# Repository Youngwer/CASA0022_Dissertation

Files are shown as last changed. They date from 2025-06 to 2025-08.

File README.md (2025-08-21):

# 🌊 AquaMonitor: Portable LoRaWAN Water Quality Monitoring System






> A portable, real-time drinking water quality monitoring system designed for public spaces, featuring multi-parameter sensing, LoRaWAN connectivity, and comprehensive web-based data visualization.

📖 **[View Full Dissertation](./Portable%20LoRaWAN-Based%20Real-Time%20Water%20Quality.pdf)

## 🎯 Project Overview

This system addresses the critical need for real-time water quality monitoring in public drinking facilities. Unlike traditional laboratory-based testing that can take hours or days, AquaMonitor provides **immediate water safety assessment** through:

- **Multi-parameter sensing**: pH, turbidity, electrical conductivity, and temperature
- **Instant feedback**: Tri-color LED indicators and e-paper display
- **Long-range connectivity**: LoRaWAN communication via The Things Network
- **Public accessibility**: Web dashboard for community monitoring
- **Portable design**: Battery-powered operation for diverse deployment scenarios
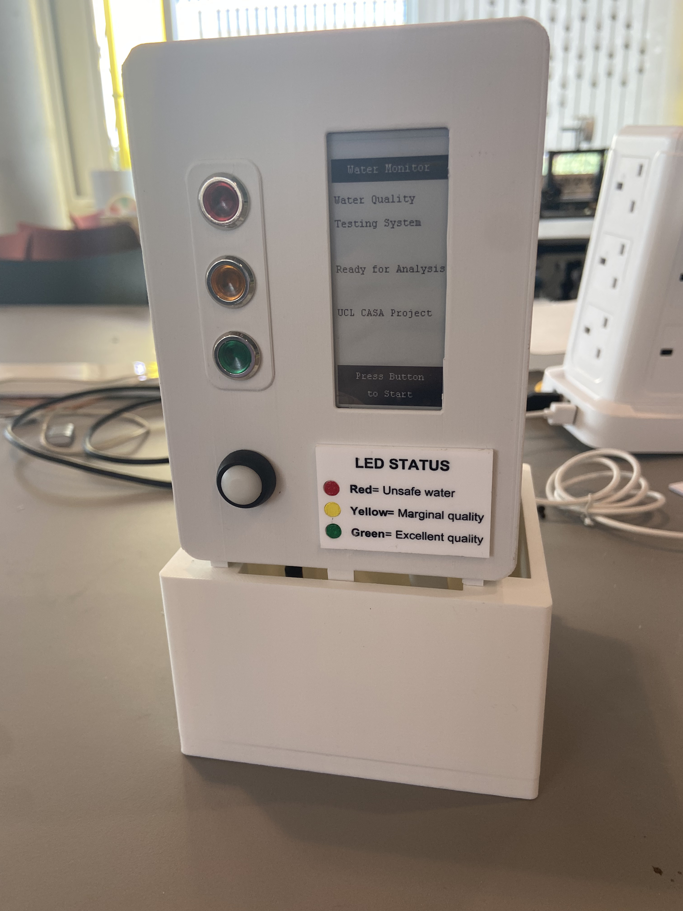
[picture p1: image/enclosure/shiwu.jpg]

### 🏆 Key Achievements
- ✅ **100% classification accuracy** according to WHO/EPA standards
- ✅ **Excellent sensor calibration** (R² = 0.9995 for pH, R² = 0.9987 for turbidity)
- ✅ **Comprehensive dataset** from UCL East Marshgate area public facilities
- ✅ **Real-time response** within 3-5 seconds of sensor immersion

## 🚀 Features

### Hardware Capabilities
- **Multi-sensor Integration**: 4 calibrated sensors for comprehensive water analysis
- **Immediate Visual Feedback**: LED indicators (🔴 Unsafe, 🟡 Marginal, 🟢 Excellent)
- **Detailed Display**: 2.9" e-paper screen with parameter readings
- **Robust Design**: 3D-printed waterproof enclosure with rubber grommets
- **Long-range Communication**: LoRaWAN connectivity (5-15km range)

### Software Features
- **Real-time Classification**: WHO/EPA standard-based water safety assessment
- **Web Dashboard**: Public access to current and historical data
- **Source Tracking**: Categorize and compare different water facilities
- **Mobile Responsive**: Optimized for both desktop and mobile viewing

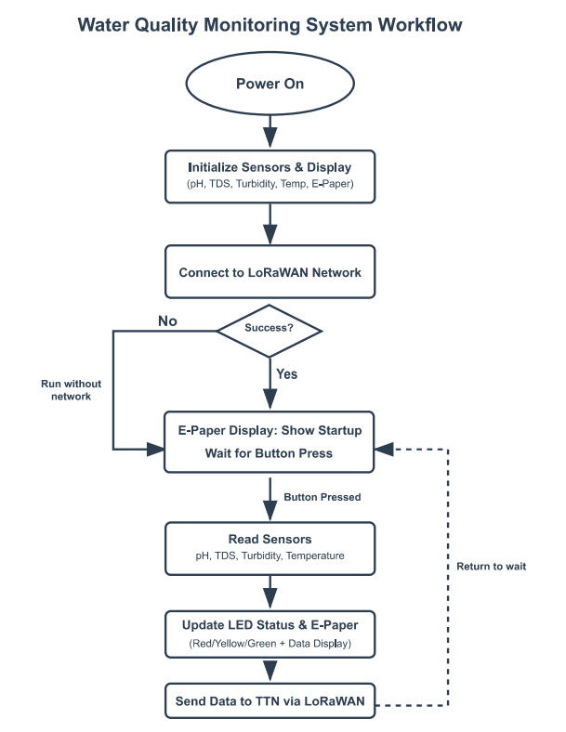
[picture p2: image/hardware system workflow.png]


## 🏗️ System Architecture

### Data Flow
```
Sensors → Arduino MKR WAN 1310 → LoRaWAN → TTN → Webhook → PostgreSQL → Web App
```

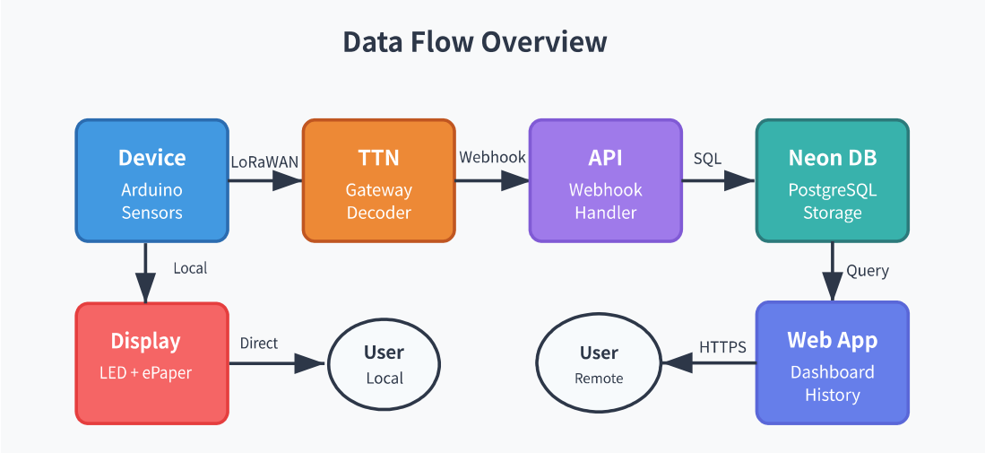
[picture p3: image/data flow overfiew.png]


### Component Overview

| Component | Function | Communication |
|---|---|---|
| **Sensors** | Water parameter measurement | Analog/Digital |
| **Arduino MKR WAN 1310** | Data processing & transmission | LoRaWAN |
| **The Things Network** | LoRaWAN network server | HTTP Webhook |
| **Neon PostgreSQL** | Data storage | SQL |
| **Next.js Web App** | Data visualization | REST API |

## 🛠️ Hardware Requirements

### Core Components
- **Arduino MKR WAN 1310** - Main microcontroller with LoRaWAN
- **DFRobot SEN0161** - pH sensor (±0.1 pH accuracy)
- **DFRobot SEN0189** - Turbidity sensor (0-1000 NTU range)
- **Conductivity Probe** - EC/TDS measurement (±2% reading accuracy)
- **DS18B20** - Waterproof temperature sensor (±0.5°C accuracy)

### Interface Components
- **2.9" E-Paper Display** - Low power consumption display
- **Tri-color LEDs** - Immediate visual feedback
- **Waterproof Push Button** - User interaction
- **3D Printed Enclosure** - Weather-resistant housing

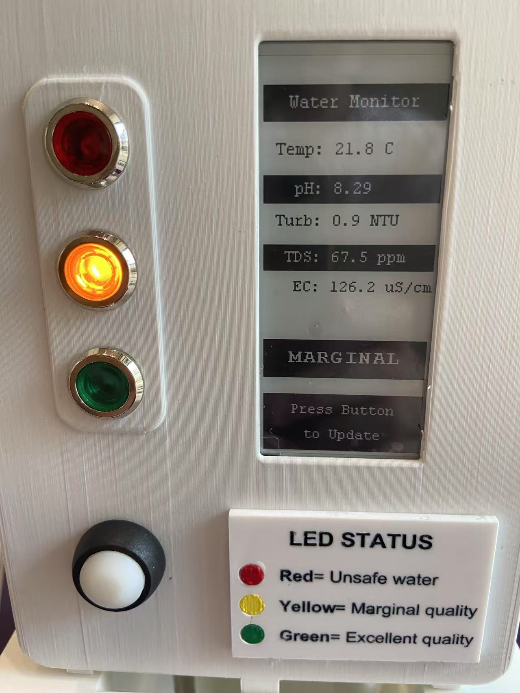
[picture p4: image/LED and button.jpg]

## 💻 Software Requirements

### Development Environment
- **Arduino IDE** 1.8.x or 2.x
- **Node.js** 18.x or later
- **Git** for version control

### Required Libraries

#### Arduino Libraries
```cpp
#include <MKRWAN.h>           // LoRaWAN communication
#include <OneWire.h>          // Temperature sensor
#include <DallasTemperature.h> // DS18B20 interface
#include <GxEPD2_BW.h>        // E-paper display
#include <Fonts/FreeMonoBold9pt7b.h>
```

#### Web Application Dependencies
```json
{
  "next": "^14.0.0",
  "react": "^18.0.0",
  "pg": "^8.11.0",
  "@vercel/postgres": "^0.5.0"
}
```

## 📥 Installation & Setup

### 1. Hardware Assembly

#### Sensor Connections
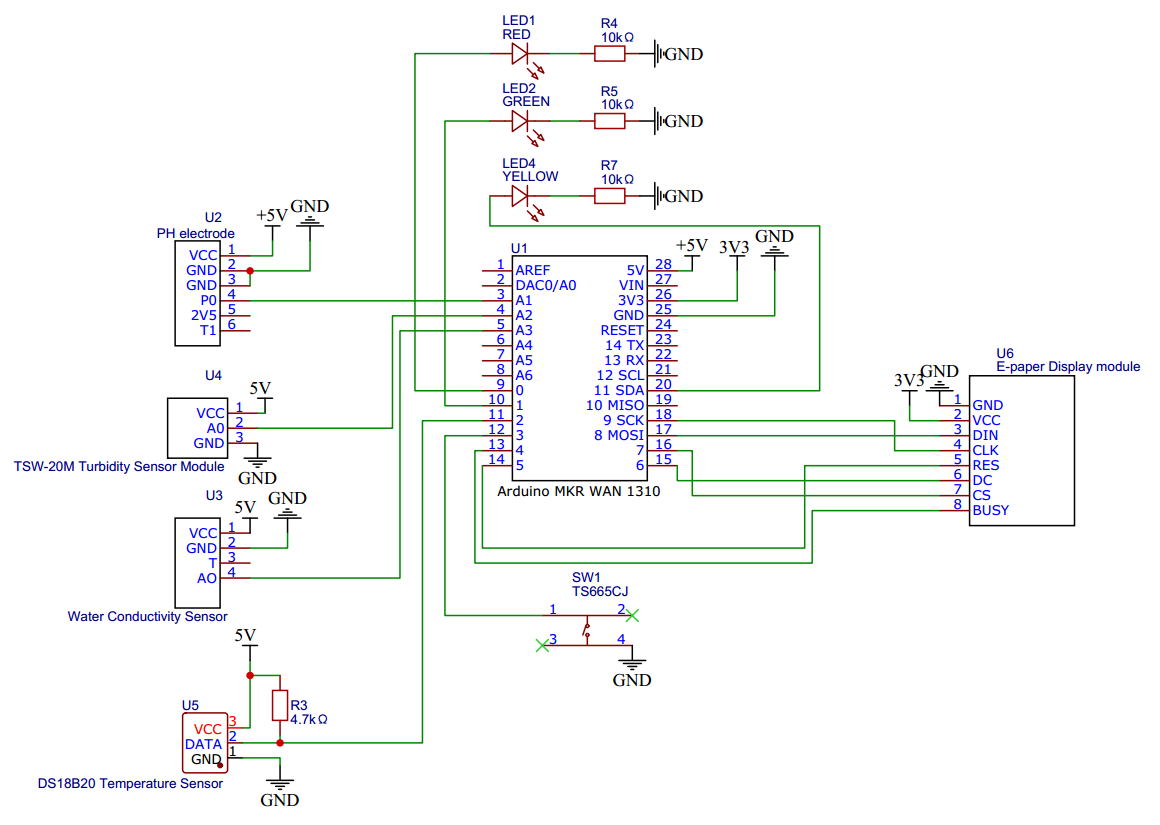
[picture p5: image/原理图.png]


| Component | Arduino Pin | Notes |
|---|---|---|
| pH Sensor | A1 | 5V power required |
| Turbidity Sensor | A2 | Via voltage divider (6.4kΩ + 6.4kΩ) |
| EC Sensor | A0 | Direct connection |
| Temperature Sensor | D6 | 4.7kΩ pull-up resistor |
| Red LED | D2 | 10kΩ current limiting resistor |
| Green LED | D3 | 10kΩ current limiting resistor |
| Yellow LED | D4 | 10kΩ current limiting resistor |
| Push Button | D1 | Pull-down configuration |
| E-Paper Display | SPI | Multiple pins (see Table 5) |

#### Enclosure 
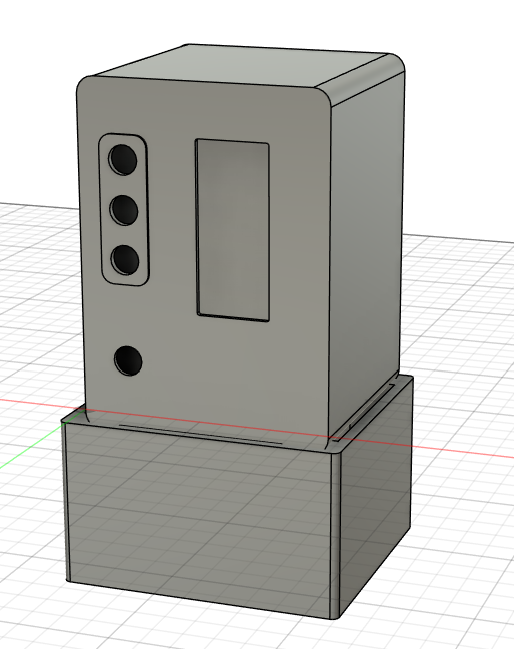
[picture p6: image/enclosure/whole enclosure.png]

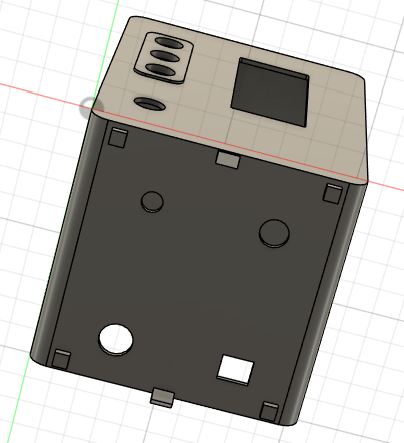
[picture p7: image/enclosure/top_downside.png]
- **Upper Housing**
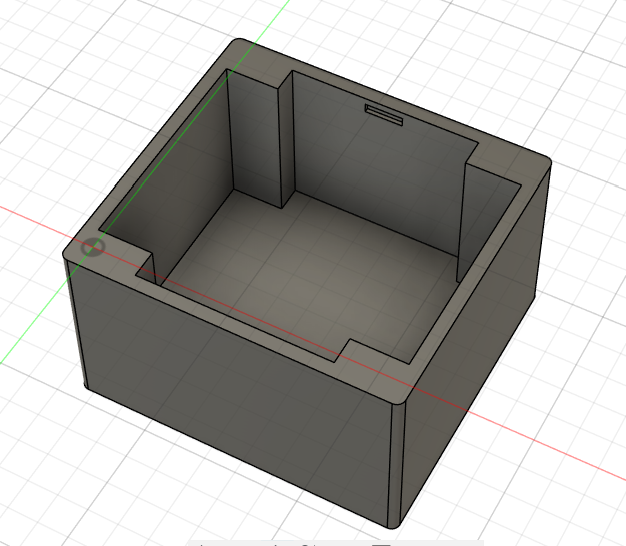
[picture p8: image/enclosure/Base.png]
- **Lower Base** 
- **Print Settings**: PLA, 0.2mm layer height, 20% infill

### 2. Arduino Setup

#### LoRa: Get Device EUI
```cpp
// Run this code first to get your DevEUI
#include <MKRWAN.h>
LoRaModem modem;

void setup() {
  Serial.begin(115200);
  if (!modem.begin(EU868)) {
    Serial.println("Failed to start module");
    while(1) {}
  };
  Serial.print("Your device EUI is: ");
  Serial.println(modem.deviceEUI());
}
```

#### Sensor Calibration

**pH Sensor Calibration**
```cpp
// Calibration equation derived from standard buffer solutions
// pH = 12.521 × Voltage - 17.79
// R² = 0.9995
```

**Turbidity Sensor Calibration**
```cpp
// Calibration equation from standard solutions
// NTU = -142.68 × Voltage + 638.92
// R² = 0.9987
```
### 3. The Things Network Configuration

#### Device Registration
1. Create account at [The Things Network](https://www.thethingsnetwork.org/)
2. Create new application: `water-quality-monitor`
3. Register device with retrieved DevEUI
4. Set frequency plan to EU868
5. Note down AppKey and AppEUI

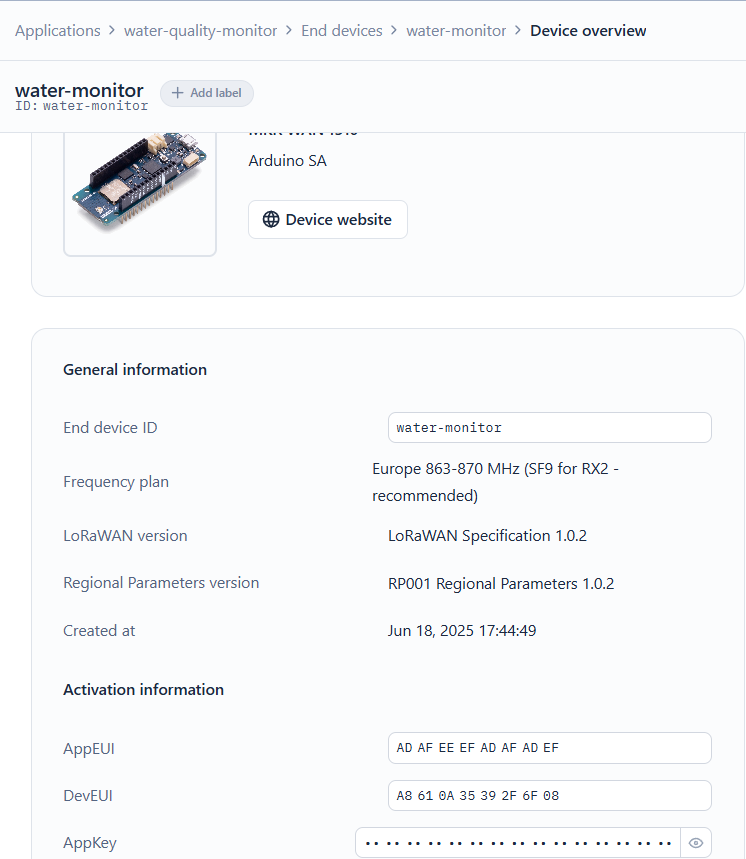
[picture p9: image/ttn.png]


#### Payload Formatter
```javascript
function decodeUplink(input) {
  var data = {};
  data.ph = ((input.bytes[0] << 8) | input.bytes[1]) / 100.0;
  data.turbidity = ((input.bytes[2] << 8) | input.bytes[3]) / 100.0;
  data.tds = (input.bytes[4] << 8) | input.bytes[5];
  data.ec = (input.bytes[6] << 8) | input.bytes[7];
  data.temperature = ((input.bytes[8] << 8) | input.bytes[9]) / 100.0;
  data.status = String.fromCharCode(input.bytes[10]);
  
  return {
    data: data,
    warnings: [],
    errors: []
  };
}
```

### 4. Database Setup

#### Neon PostgreSQL
1. Create account at [Neon](https://neon.tech/)
2. Create new database: `water_quality_monitor`
3. Run schema setup:

```sql
CREATE TABLE measurements (
  id SERIAL PRIMARY KEY,
  ph DECIMAL(4,2),
  turbidity DECIMAL(6,2),
  tds INTEGER,
  ec INTEGER,
  temperature DECIMAL(4,2),
  status VARCHAR(10),
  water_source VARCHAR(100),
  timestamp TIMESTAMPTZ DEFAULT NOW()
);

CREATE INDEX idx_timestamp ON measurements(timestamp);
CREATE INDEX idx_status ON measurements(status);
```

### 5. Web Application Deployment

#### Local Development
```bash
# Clone repository
git clone https://github.com/Youngwer/CASA0022_Dissertation.git
cd CASA0022_Dissertation/web

# Install dependencies
npm install

# Set environment variables
cp .env.example .env.local
# Edit .env.local with your database URL

# Run development server
npm run dev
```

#### Vercel Deployment
```bash
# Install Vercel CLI
npm i -g vercel

# Deploy
vercel --prod
```

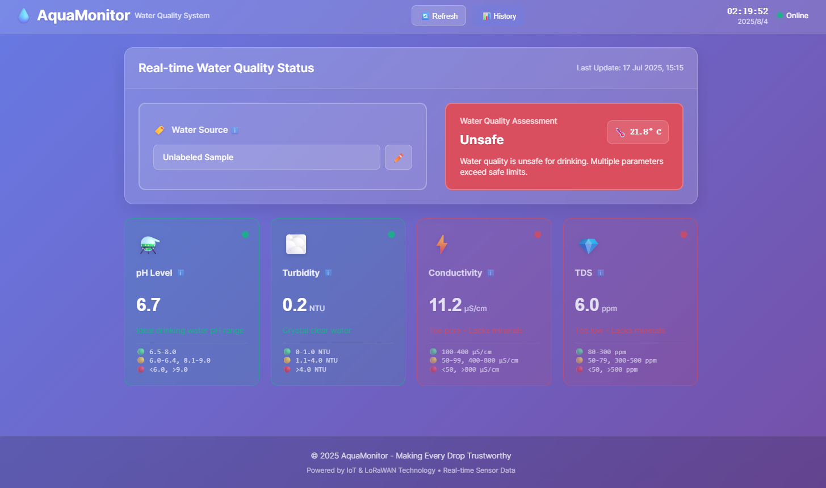
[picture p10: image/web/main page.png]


## 🔧 Usage Instructions

### Device Operation

1. **Power On**: Connect USB power supply
2. **Wait for Initialization**: E-paper displays home screen
3. **Immerse Sensors**: Place all four sensors in water sample
4. **Press Button**: Activate measurement cycle
5. **Read Results**: 
   - LED color indicates overall water safety
   - E-paper shows detailed parameters
   - Data automatically transmitted via LoRaWAN

### Water Quality Classification

| Status | LED Color | Criteria |
|---|---|---|
| **Excellent** | 🟢 Green | All parameters within optimal WHO ranges |
| **Marginal** | 🟡 Yellow | Safe but some parameters in acceptable ranges |
| **Unsafe** | 🔴 Red | One or more parameters exceed safety limits |

#### Parameter Thresholds

| Parameter | Excellent | Marginal | Unsafe |
|---|---|---|---|
| pH | 6.5 - 8.0 | 6.0-6.4, 8.1-9.0 | <6.0, >9.0 |
| Turbidity (NTU) | 0 - 1.0 | 1.1 - 4.0 | >4.0 |
| TDS (ppm) | 80 - 300 | 50-79, 301-500 | <50, >500 |
| EC (μS/cm) | 100 - 400 | 50-99, 401-800 | <50, >800 |

### Web Dashboard Features

- **Real-time Status**: Current water quality with color-coded background
- **Parameter Details**: Individual sensor readings with timestamps
- **Historical Data**: Sortable table of past measurements
- **Source Tracking**: Filter by water source type
- **Data Export**: Download CSV for further analysis

## 📁 Repository Structure

```
CASA0022_Dissertation/
├── arduino/
│   ├── device_main/              # Main device firmware
│   │   └── device_main.ino
│   ├── sensor_tests/             # Individual sensor test codes
│   │   ├── ph_test.ino
│   │   ├── turbidity_test.ino
│   │   ├── ec_test.ino
│   │   └── temperature_test.ino
│   └── calibration/              # Sensor calibration utilities
│       ├── ph_calibration.ino
│       └── turbidity_calibration.ino
├── web/
│   ├── components/               # React components
│   ├── pages/                    # Next.js pages
│   ├── styles/                   # CSS stylesheets
│   ├── utils/                    # Utility functions
│   └── public/                   # Static assets
├── hardware/
│   ├── 3d_models/               # STL files for enclosure
│   │   ├── upper_housing.stl
│   │   └── lower_base.stl
│   ├── schematics/              # Circuit diagrams
│   └── pcb/                     # PCB design files (if applicable)
├── docs/
│   ├── Dissertation.pdf         # Complete dissertation
│   ├── calibration_guide.md     # Sensor calibration procedures
│   ├── deployment_guide.md      # Field deployment instructions
│   └── troubleshooting.md       # Common issues and solutions
├── data/
│   ├── sample_dataset.csv       # Example measurement data
│   └── calibration_data/        # Sensor calibration records
└── README.md
```

## 🌍 Deployment Locations

This system has been successfully tested across diverse public facilities in the UCL East Marshgate area:

- **University Campus**: Water fountains and bathroom taps
- **Shopping Centers**: Westfield Avenue public fountains  
- **Public Parks**: Queen Elizabeth Olympic Park facilities
- **Commercial Areas**: Various retail space water sources

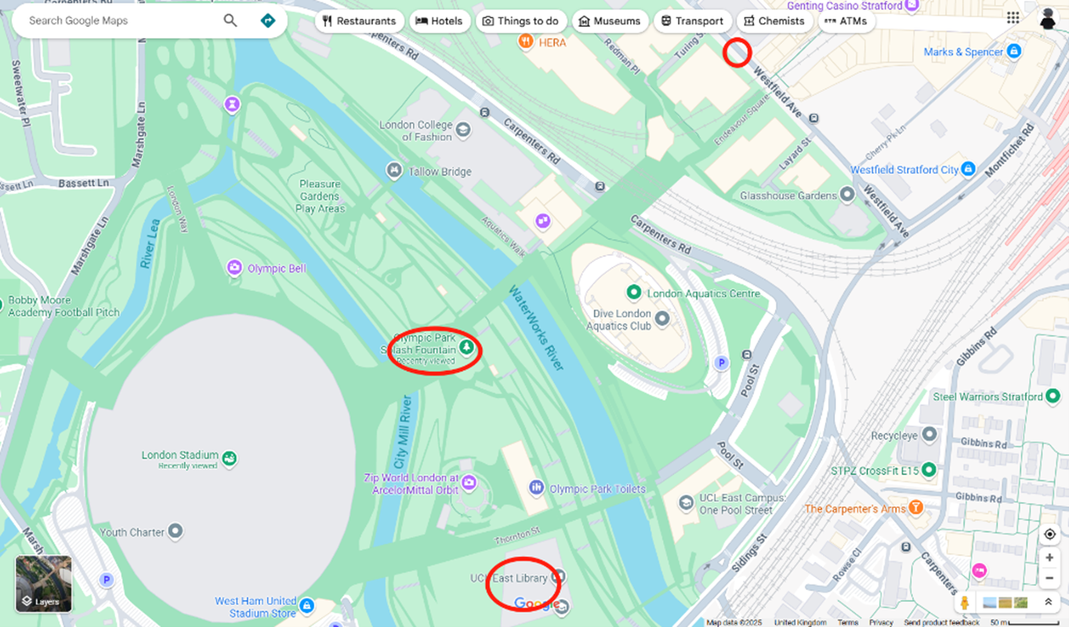
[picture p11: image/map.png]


### Field Testing Results

| Location | Water Quality | Key Findings |
|---|---|---|
| UCL Marshgate Fountain | Excellent | Consistent 🟢 ratings across multiple tests |
| Olympic Park Plaza | Excellent | Slightly higher TDS than campus sources |
| Westfield Public Fountain | Excellent | Higher mineral content (245 ppm TDS) |
| Campus Bathroom Tap | Excellent | Similar quality to fountain sources |

## 🤝 Contributing

We welcome contributions to improve AquaMonitor! Here's how you can help:

### Improvements
- Additional sensor integration
- Weatherproofing enhancements
- Mobile application development

### How to Contribute
1. Fork the repository
2. Create a feature branch (`git checkout -b feature/AmazingFeature`)
3. Commit your changes (`git commit -m 'Add some AmazingFeature'`)
4. Push to the branch (`git push origin feature/AmazingFeature`)
5. Open a Pull Request

## 📊 Performance Metrics

### Sensor Accuracy
- **pH Sensor**: ±0.13 pH units (±3.25% max error)
- **Turbidity Sensor**: ±1.68 NTU (±3.65% max error)  
- **Temperature Sensor**: ±0.5°C (manufacturer specification)
- **EC Sensor**: ±2% reading (manufacturer specification)

### System Performance
- **Response Time**: 3-5 seconds for complete measurement
- **Classification Accuracy**: 100% according to WHO/EPA standards
- **LoRaWAN Range**: Successfully tested up to 2km radius
- **Data Transmission**: 100% success rate across test locations

### Power Consumption
- **Measurement Mode**: ~150mA (USB powered)
- **Sleep Mode**: <1mA (future battery implementation)
- **Display Update**: ~50mA for 2 seconds

## 🛠️ Troubleshooting

### Common Issues

#### Sensor Reading Errors
- **pH Probe**: Ensure proper conditioning in storage solution
- **Turbidity Sensor**: Check voltage divider connections
- **EC Sensor**: Verify probe cleanliness and calibration
- **Temperature**: Confirm OneWire library installation

#### Web Dashboard Issues
- Check environment variables in `.env.local`
- Verify database connection string
- Ensure webhook URL matches deployment URL

### Calibration Maintenance
- **pH Sensor**: Recalibrate monthly with buffer solutions
- **Turbidity Sensor**: Clean optical surfaces weekly
- **EC Sensor**: Use standard conductivity solutions for verification
- **All Sensors**: Store properly when not in use

## 📄 License

This project is licensed under the MIT [License](https://opensource.org/license/mit).

## 📞 Contact & Support

**Author**: Wenhao Yang  
**Institution**: UCL Centre for Advanced Spatial Analysis  
**Supervisor**: Martin de Jode  
**Module**: CASA0022 - Connected Environments MSc

### Get in Touch
- 📧 **Email**: ucfnwy2@ucl.ac.uk
- 🐱 **GitHub**: [@Youngwer](https://github.com/Youngwer)
- 📄 **Dissertation**: [Full PDF](./Portable%20LoRaWAN-Based%20Real-Time%20Water%20Quality.pdf)
- 🐛 **Bug Reports**: [GitHub Issues](https://github.com/Youngwer/CASA0022_Dissertation/issues)

---

## 🙏 Acknowledgments

Special thanks to:
- **Martin de Jode** - Project supervisor and technical guidance
- **Danny Steadman & Simon Gosling** - Light Fabrication Workshop support
- **UCL CASA** - Facilities and equipment access
- **The Things Network** - LoRaWAN infrastructure
- **Open Source Community** - Libraries and tools

---

<div align="center">

**🌊 Making water quality monitoring accessible to everyone 🌊**

[⬆ Back to Top](#-aquamonitor-portable-lorawan-water-quality-monitoring-system)

</div>

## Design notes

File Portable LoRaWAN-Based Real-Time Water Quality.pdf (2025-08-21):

## Portable LoRaWAN-Based Real-Time Drinking

## Water Quality Monitoring System for Public

## Spaces

## Author: Wenhao Yang

## Supervisor: Martin de Jode

## Module: CASA0022

### Github Repo: https://github.com/Youngwer/CASA0022_Dissertation

## Wordcount: 5798

- [excluding tables, figures, captions, title page,

### acknowledgements, references, abstract and appendices]

### This dissertation is submitted in part requirement for the MSc in the

### Centre for Advanced Spatial Analysis, Bartlett Faculty of the Build

Environment, UCL.

## Declaration of Authorship:

### I, Wenhao Yang, confirm that the work presented in this assessment is my

own and that all sources have been acknowledged.

### ASSESSMENT DATE: 22/08/2025

## Abstract

Access to safe drinking water remains a global issue, with approximately 2 billion

people relying on contaminated drinking water sources according to the World Health

Organization. Public drinking facilities, such as water fountains in universities, parks,

and commercial spaces, often lack real-time water quality assessment, instead, relying

heavily on periodic laboratory testing which is time-consuming and may not detect

contamination immediately.

Studies have shown that Internet of Things (IoT) technologies have the potential to

offer continuous and automated surveillance that would improve the safety of the

overall health of the public. Due to the widespread distribution of public drinking

facilities, the deployment of drinking water monitoring devices is hard to achieve

comprehensive coverage as this device are usually fixed and expensive.

This paper presents an innovative portable monitoring system integrating multiple

sensors (pH, turbidity, electrical conductivity, temperature) with LoRaWAN

communication to The Things Network (TTN). The low-cost IoT device features

multi-level user interaction through LED indicators, e-paper display, and web

dashboard, providing immediate water quality assessment based on WHO standards

and categorizing safety as “Excellent”, “Marginal”, “Unsafe”. The effectiveness of the

system has been demonstrated in the field testing across UCL East area drinking

points with successful testing results gained for public space implementation.

## Acknowledgements

I would like to express my gratitude to my supervisor, Martin de Jode, for his constant

inspiration and assistance throughout this process. His invaluable design advice,

encouragement, detailed guidance in providing appropriate equipment, and

comprehensive thesis supervision have been instrumental in the successful completion

of this project.

I would also like to thank Danny Steadman and Simon Gosling from the Light

Fabrication Workshop for their expert assistance with the 3D printing enclosure and

their support during the exhibition phase of this research.

## 1. Introduction

### 1.1 Research Background

In the United Kingdom, drinking water quality is generally maintained at a high

standard, with public water supply systems achieving a compliance rate of over

99.98%(Drinking Water Inspectorate, 2024). However, challenges exist, particularly

with public drinking facilities such as water fountains and taps, which can pose health

risks if not properly maintained.

Research indicates that inadequate cleaning can lead to bacterial contamination in

these facilities, especially in high-traffic areas like schools, parks, and train stations

(The Guardian, 2018). Additionally, aging infrastructure, such as lead pipes in older

buildings, contributes to localised contamination risks, with lead compliance rates

slightly lower at 99.6%(Drinking Water Inspectorate, 2024). Recent concerns have

also emerged regarding the presence of per- and polyfluoroalkyl substances (PFAS),

or “forever chemicals,” in some English drinking water sources, prompting calls for

stricter regulations(The Guardian, 2025).These issues highlight the need for enhanced

monitoring to ensure public water safety.

Public drinking fountains, as the main source for providing drinking water in the

public place, face significant safety concerns due to potential contamination. Studies

indicate that water fountains can harbour bacteria, and the bacterial colony counts in

public drinking fountains can be alarmingly high, particularly in high-traffic areas like

airports and shopping malls(Bichelman, 2024). For instance, a 2018 investigation

found that some public fountains in London had disappeared due to poor maintenance

and concern about health risks(The Guardian, 2018).

To solve the potential contamination problem of public facilities, water quality testing

is essential for the public health. Traditional laboratory-based water quality testing,

while essential, has notable limitations. This approach has several drawbacks,

including the high cost of labour and equipment, along with a lack of real-time

information about drinking water quality that can facilitate critical decisions to ensure

public safety(Vijayakumar and Ramya, 2015). Moreover, periodic sampling fails to

capture real-time fluctuations in water quality, limiting the ability to respond promptly

to contamination events(Zainurin et al., 2022). These limitations underscore the need

for more real-time monitoring solutions in public spaces.

This research aims to design and build a real-time water quality tester for public

drinking facilities through the communication of LoRaWAN with multi-parameter

sensors. The system shows water quality results via LED indicators and an e-paper

display for immediate feedback, alongside a web-based dashboard for detailed

visualization of water quality parameters. Public drinking fountains in the areas near

UCL East Marshgate were selected as the study area for this research. The project will

generate a dataset accessible in the project repository, with the assumption that the

information presented on the web dashboard may benefit stakeholders, including local

authorities and future water quality studies.

### 1.2 Research Questions and Objectives

1. Can a portable, low-cost, drinking water monitoring device be developed to

provide the public with immediate water quality safety information in urban areas

such as the UCL East Marshgate?

2. What are the water quality differences between different public drinking

facilities, such as university campus and commercial places, and can portable

monitoring effectively characterise these variations?

The objective of the project is to design and implement a portable, low-cost drinking

water quality monitoring system utilising LoRaWAN technology, alongside an

interactive web platform, to actively monitor and improve public awareness of water

quality safety at public drinking facilities near UCL East area.

### 1.3 Structure of the Dissertation

This dissertation is structured into six chapters, beginning with an Introduction

that outlines the research context and objectives. After the Introduction, a critical

review of literature on water quality monitoring and IoT-based sensor systems is

presented (Chapter 2), followed by a detailed design and implementation of the

portable drinking water monitoring system (Chapter 3), The collected data and

experimental results are presented in Chapter 4, with Chapter 5 discussing key

findings, limitations, and reflections, while Chapter 6 concluding this project while

identifying possible future research opportunities.

## 2. Literature Review

### 2.1 Water Quality Monitoring Methods: Evolution and Comparison

Drinking water quality monitoring is critical for safeguarding public health and

ensuring sustainable water resources. Since the late 20th century, drinking water quality

monitoring has evolved significantly, transitioning from reliance on traditional

laboratory testing to advanced, real-time technologies. Traditional methods, involving

chemical and biological analyses, offer high precision but are time-consuming and

costly (Vijayakumar and Ramya, 2015). The advent of electronic sensors enabled rapid

measurement of parameters like pH, turbidity, residual chlorine, and dissolved oxygen,

improving response times and data accuracy(Badger Meter, 2023). In the 21st century,

IoT technologies, leveraging low-power, long-range communication protocols such as

LoRaWAN and GSM, have transformed monitoring by enabling smart sensors to

transmit real-time data to cloud platforms, suitable for both urban and remote

settings(Zainurin et al., 2022). Remote sensing technologies, including satellites and

drones, have emerged as powerful tools for large-scale water quality assessment,

offering broad spatial coverage despite limitations in parameter specificity (Li et al.,

2021). Optical and spectroscopic methods, such as ultraviolet-visible spectroscopy

(UV-Vis) and fluorescence spectroscopy, offer non-invasive, rapid detection of turbidity,

dissolved organic matter, and microbial contaminants, minimizing chemical reagent use

(Jiang and Meng, 2015). The integration of artificial intelligence (AI) and machine

learning (ML) has further enhanced monitoring capabilities by enabling predictive

analytics and anomaly detection. These technologies analyse large datasets to identify

potential | contamination | risks | before | they | escalate, | improving | proactive

management(Zainurin et al., 2022). These advancements collectively underscore a shift

toward scalable, efficient systems prioritizing real-time data and public safety.

To comprehensively evaluate current drinking water quality monitoring strategies, the

following table compares five primary methods based on their advantages and

disadvantages.

Table 1. Summary of water quality monitoring approaches

Monitoring Method | Pros | Cons
Traditional Laboratory | High accuracy | Time-consuming, manual, high cost, less effective for continuous

Testing | | monitoring (Vijayakumar and Ramya, 2015)
On-Site Sensors | • Real-time data collection • monitors multiple parameters, • cost-effective(Badger Meter, 2023) | • Requires regular calibration and maintenance • accuracy may degrade over time • limited to specific parameters • needs power supply(Zainurin et al., 2022)
IoT Monitoring Systems | • Real-time wireless data transmission and quick alert • cost-effective in long-term | • Reliant on network coverage • potential cybersecurity risks • high initial investment(Fields, no date)
Remote Sensing | Large-scale and real-time monitoring and non-contact | • Limited parameter(turbidity and algae) measurement(NASA, 2023) • affected by weather and resolution, • high application cost(Yang et al., 2022)
Optical/Spectroscopic Methods | • High sensitivity and rapid • reagent-free detection of turbidity and organic matter • real-time monitoring(Thomas, Delpla and Thomas, 2017) | • Requires calibration • susceptible to interference • high equipment costs(Hossain et al., 2020)

### 2.2 Related Work

Recent research has demonstrated the technical feasibility of portable water quality

monitoring. Kelechi et al. (2021) developed portable systems integrating temperature,

pH, and turbidity sensors with microcontroller processing and Bluetooth connectivity

for Android applications, achieving high measurement accuracy (97-100%) while

demonstrating cost-effective monitoring capabilities for the community but suffering

from limited communication range(Hilary Kelechi et al., 2021). The WaterScope

platform by Bedell et al. (2024) further validated this approach through extensive

laboratory and field testing. Through the introduction of open-source portable testing

with machine learning-enhanced classification technology, it can establish equivalent

measurement with conventional laboratory methods(Dabrowska et al., 2024).

Most existing portable monitoring research focuses on natural water environments

such as rivers and lakes. Liu et al. (2018) developed a solar-powered LoRaWAN

system achieving stable data transmission every 30 minutes with minimal data loss,

though their focus remained on controlled water bodies rather than public drinking

facilities(Liu et al., 2018). Pires et al. (2024) implemented practical river monitoring

solutions measuring temperature, pH, conductivity, and turbidity with real-time

LoRaWAN transmission, achieving average RSSI of -94 dBm and SNR of 7.33 dB

during 4-hour field deployments(Pires and Gomes, 2024). (Jabbar et al., 2024).

Demetillo et al. (2019) deployed buoy-based systems for large aquatic area

monitoring that maintained stability even under extreme weather conditions, including

tropical cyclones with 95 km/h winds. (Demetillo, Japitana and Taboada, 2019).

Limited research has addressed portable monitoring specifically for public drinking

facilities. Kelechi et al. (2021) developed portable systems with Bluetooth

connectivity for community monitoring, but their approach suffered from limited

communication range requiring manual data collection, making it unsuitable for

distributed public facility monitoring.(Hilary Kelechi et al., 2021). Miao et al. (2022)

implemented campus-wide monitoring systems using LoRaWAN for both air and

water quality, noting cost-effectiveness and scalability potential, though their work

lacked detailed accuracy validation and focused primarily on environmental

monitoring rather than public drinking safety assessment(Miao et al., 2022).

Critical Research Gap: Existing portable water quality monitoring research focuses primarily on natural water bodies or laboratory conditions, with limited investigation

of public drinking facilities. This gap represents a missed opportunity for the public to

understand drinking water quality variations across different facility types, such as in

the shopping mall and university campus, which could be valuable information for

public health.

## 3. Methodology

### 3.1 System Overview

This section provides an overview of the portable water quality monitoring system

architecture and its operational workflow. The hardware system comprises four main

components: a multi-parameter sensor system for water quality measurement, an

Arduino MKR WAN 1310 microcontroller with integrated LoRaWAN connectivity, a

dual-feedback user interface with LED indicators and ePaper display. In terms of the

software system, a database is used for data storage and Web platform to visualise

water quality information and histories.

The main objectives of this research were to measure water quality parameters,

provide immediate user feedback, and transmit data for longitudinal analysis. To

achieve these goals, a portable device was developed that integrates four water quality

sensors (pH, EC, turbidity, temperature) with Arduino MKR WAN 1310. The device

was programmed to provide instant visual feedback through tri-colour LED indicators

and ePaper display, while simultaneously transmitting data via LoRaWAN to The

Things Network (TTN) gateway. Following this, a configured webhook handler

processes the data from TTN and stores it in a Neon PostgreSQL database, while a

Next.js web application was developed to provide historical data visualization and

water source tracking capabilities.

The documentation of this research, which includes sensor calibration procedures,

hardware schematics, embedded software code, web application source code, and

deployment guidelines, can be accessed through the project repository at GitHub. (https://github.com/Youngwer/CASA0022_Dissertation) The

Appendix A presents a bill table for the component list.

### 3.2 Sensors and Calibration

Four sensors were used to measure key water quality parameters: pH, electrical conductivity, turbidity, and temperature. Some of these sensors need to be calibrated

before testing.

DS18B20 Temperature Sensor

The DS18B20(Figure 1) is a low-cost, robust digital temperature sensor which

operates underwater with ±0.5°C accuracy. This waterproof sensor was chosen due to

its reliability, direct digital output compatibility with Arduino platforms, and

elimination of analogue-to-digital conversion errors. No calibration was required for

this sensor, and it can provide temperature data for water quality and enable

temperature compensation for other sensors which are affected by temperature when

testing.

Figure 1. DS18B20 Waterproof Temperature Sensor

pH Sensor

The DFRobot SEN0161 analogue pH sensor was selected for measuring water acidity

and alkalinity levels due to its cost-effectiveness and easy-to-use features. This probe-

based sensor operates in the pH range of 0-14 with ±0.1 pH accuracy at 25°C, suitable

for drinking water assessment. The sensor requires 5V power supply. Prior to use, the

probe was conditioned in storage solution for 12-24 hours to activate the glass

electrode membrane. As shown in Figure 2, there are pH electrode storage solution to

maintain the accuracy of the probe at the bottom of the glass. The sensor needs to be

calibrated to use. Figure 3 shows the standard buffer solutions (pH 4.00, 7.00, and

10.01) and electrode storage solution used for the three-point calibration performed at

approximately 25°C. The experimental data revealed an unusual voltage trend where

voltage increased with pH (pH 4.0: 1.73V, pH 7.0: 1.98V, pH 10.01: 2.21V). A linear

calibration equation was derived as below:

pH = 12.521 × Voltage - 17.79

R² = 0.9982

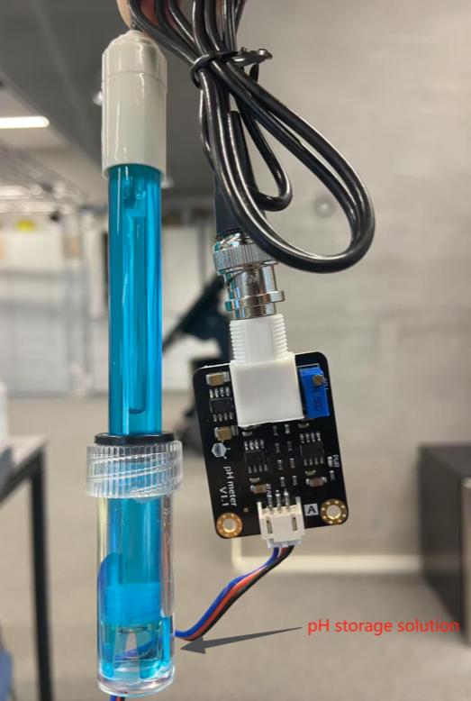
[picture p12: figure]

Figure 2. pH sensor with storage solution at the probe

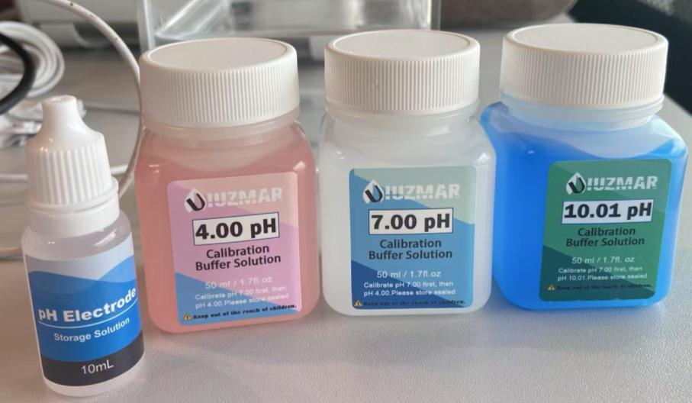
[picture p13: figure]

Figure 3. Standard buffer solutions (pH 4.00, 7.00, and 10.01)

For detailed information, the table 3 below presents the complete calibration results

with a calibration curve in Figure 4.

Table 2. pH sensor calibration results

Standard pH | ADC Reading | Voltage (V) | Calculated pH | Error | Error (%)
4.00 | 536 | 1.73 | 3.87 | +0.13 | +3.25%
7.00 | 615 | 1.98 | 7.00 | 0.00 | 0.00%
10.01 | 687 | 2.21 | 9.88 | +0.13 | +1.30%

Figure 4. pH sensor Calibration Curve

TDS and EC sensor

Total Dissolved Solids (TDS) and Electrical Conductivity (EC) (shown in Figure 5)

are critical parameters for assessing drinking water quality. TDS measures the total

concentration of dissolved substances in water, while EC measures the solution's

ability to conduct electrical current. These parameters are closely related, as

conductivity is proportional to the ionic concentration in water, and TDS is typically

estimated through conductivity measurements combined with conversion factors.

However, during laboratory testing, significant interference was observed when both

sensors operated simultaneously in the same water sample. This interference

manifested as reading deviations of 50-150 ppm TDS compared to individual

measurements to both sensors. The likely mechanism is electric field interference.

Both sensors apply AC signals to measure ionic conductivity. When operating in close

proximity, their electric fields interact and alter ion distribution in the solution, creating cross-talk that affects measurement accuracy(Vernier, 2019).

To eliminate sensor interference while maintaining measurement capability for both

parameters, the electrical conductivity sensor was selected as the only measurement

device and TDS values are calculated from conductivity readings using the

established relationship: TDS (ppm) = Conductivity (μS/cm) × 0.65. This conversion

factor of 0.65 is based on empirical studies and represents a commonly accepted

approximation for natural waters and drinking water applications(Environmental

Measurement Systems, 2014).

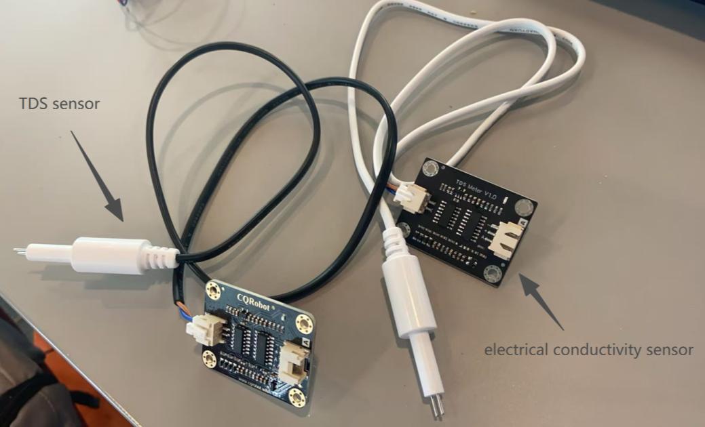
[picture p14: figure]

Figure 5. TDS sensor and EC sensor

Turbidity Sensor

The DFRobot SEN0189 analogue turbidity sensor (Figure 6) was chosen to measure

water clarity by detecting suspended particles using light scattering detection method.

The sensor operates in the range of 0-1000 NTU, suitable for drinking water analysis.

It operates in a range of 0–4.5V while the maximum ADC voltage output for the

MCU (Arduino MKR1310) is 3.3V. To prevent this damage, a voltage divider using

two 6.4kΩ resistors, reducing the voltage by half. This makes the input range 0–

2.25V, which is safe for the 3.3V ADC. Voltage readings were taken and converted

back to original sensor voltage by multiplying by 2.

The system was calibrated using a linear regression model based on the two standard

points using 20 NTU and 500 NTU turbidity solutions which is shown below in

Figure 7.

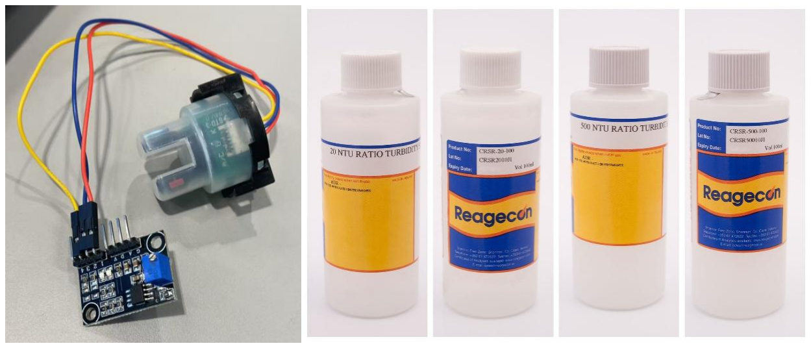
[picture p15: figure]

Figure 6. DFRobot SEN0189 Turbidity Sensor (Left)

Figure 7. Turbidity Solution (20 NTU 50NTU) (Right)

The experimental data revealed a trend which is shown in Figure 8 where the voltage

decrease with NTU (NTU 20: 2.167, NTU500: 0.485V). A linear calibration equation

was derived as below and the detailed results is in Table 4:

NTU = -142.68 × Voltage + 638.92

Table 3 Turbidity Sensor Calibration Results

Standard NTU | ADC Reading | A5 Voltage (V) | Sensor Voltage (V) | Calculated NTU | Error (NTU) | Error (%)
20.0 | 672 | 2.167 | 4.334 | 20.73 | +0.73 | +3.65%
500.0 | 150 | 0.485 | 0.970 | 498.32 | -1.68 | -0.34%

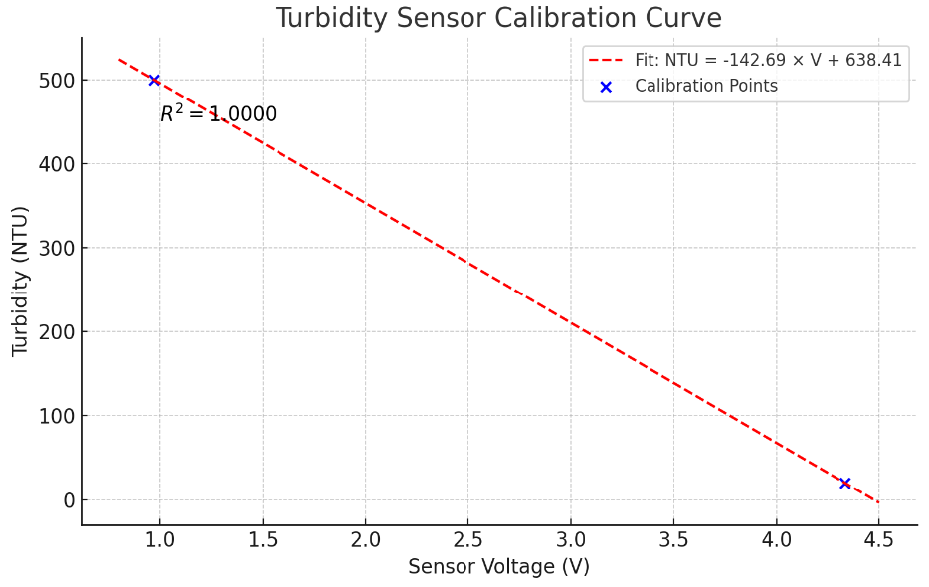
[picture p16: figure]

Figure 8. Turbidity Sensor Calibration Curve

### 3.3 Hardware Design

The water quality monitoring system was designed for portable applications and also

remote access, allowing immediate water quality assessment with real-time feedback

and cloud connectivity. The device was based on a microcontroller Arduino MKR

WAN 1310 with integrated LoRaWAN connectivity

(https://docs.arduino.cc/hardware/mkr-wan-1310) to send data to the TTN as a cloud

platform.

Hardware overview

The hardware of the device comprises the aforementioned four water quality sensors

(pH, TDS, turbidity, temperature), a tri-colour LED indicator system activated by a

push button for measurement update, and a 2.9-inch ePaper display for detailed

parameter information. The system operates via USB power supply to ensure

consistent power delivery during measurement sessions.

Table 4 provides an explanation of the components and wiring connections, whereas

Figure 9 shows the workflow of the whole system while Figure 10 shows the

complete system schematic.

Figure 9. Workflow chart of the Hardware System

Table 4. Components and Wiring List

Component | Pin | Arduino Pin | Other Connection
pH Sensor Module (U2) | VCC | +5V
| GND | GND
| P0 | A1
Turbidity Sensor (U4) | VCC | +5V
| A0 | A2 | Via voltage divider (6.4kΩ + 6.4kΩ)
| GND | GND
EC Sensor (U3) | VCC | +5V

| A0 | A0
| GND | GND
DS18B20 Temperature (U5) | VCC | +5V
| DATA | D6 | Via 4.7kΩ pullup resistor (R3)
| GND | GND
Red LED (LED1) | + | D2 | Via 10kΩ resistor (R4)
| - GND
Green LED (LED2) | + | D3 | Via 10kΩ resistor (R5)
| - GND
Yellow LED (LED4) | + | D4 | Via 10kΩ resistor (R7)
| - GND
Push Button (SW1) | 1 | D1
| 3 | GND
ePaper Display (U6) | GND | GND
| VCC | +3V3
| DIN | D11/MOSI
| CLK | D9/SCK
| CS | D7
| DC | D8
| RES | D12
| BUSY | D10

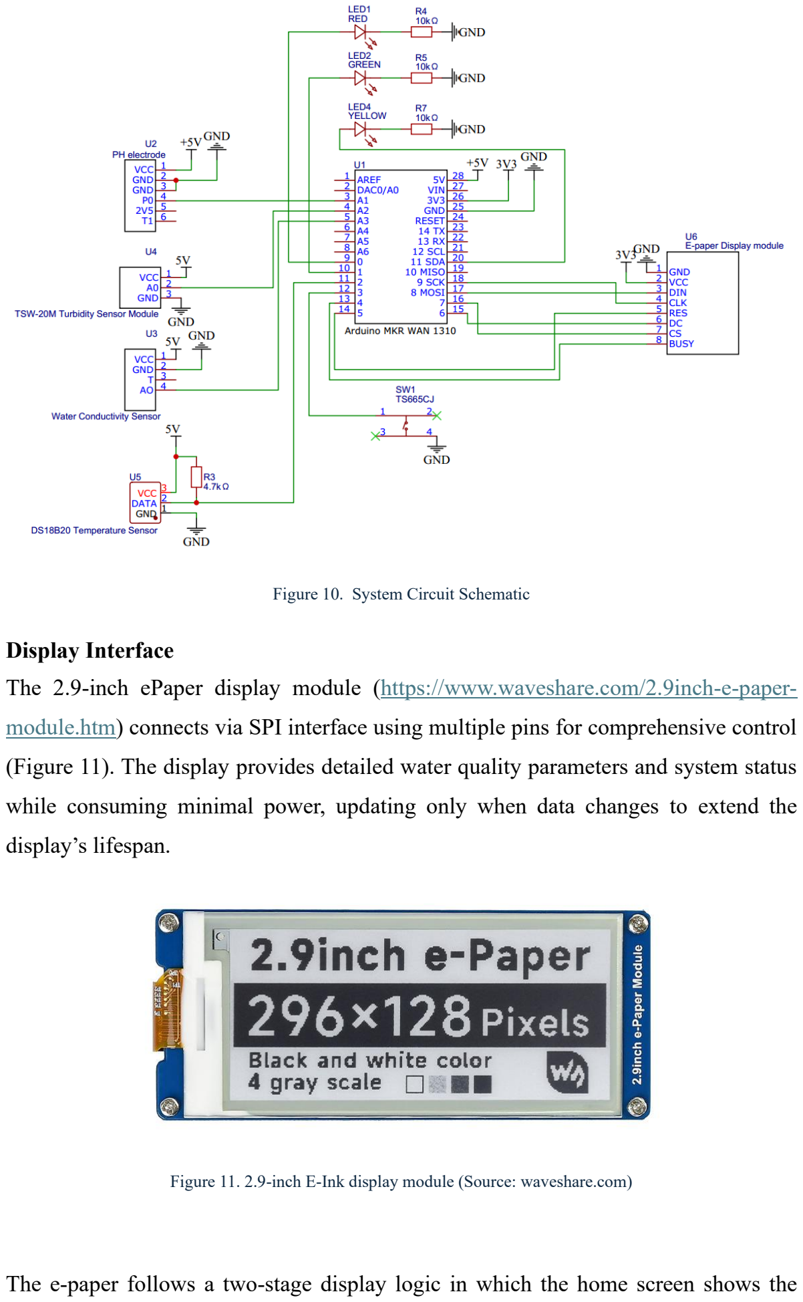
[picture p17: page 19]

Figure 10. System Circuit Schematic

Display Interface

The 2.9-inch ePaper display module (https://www.waveshare.com/2.9inch-e-paper-

module.htm) (https://www.waveshare.com/2.9inch-e-paper-module.htm) connects via SPI interface using multiple pins for comprehensive control

(Figure 11). The display provides detailed water quality parameters and system status

while consuming minimal power, updating only when data changes to extend the

display’s lifespan.

Figure 11. 2.9-inch E-Ink display module (Source: waveshare.com)

The e-paper follows a two-stage display logic in which the home screen shows the project title, system description, and readiness status, prompting the user to press the

button to begin measurement (Figure 12a). After activation, the display transitions to

the measurement screen, presenting the analysed results and an overall water quality

assessment (Figure 12b).

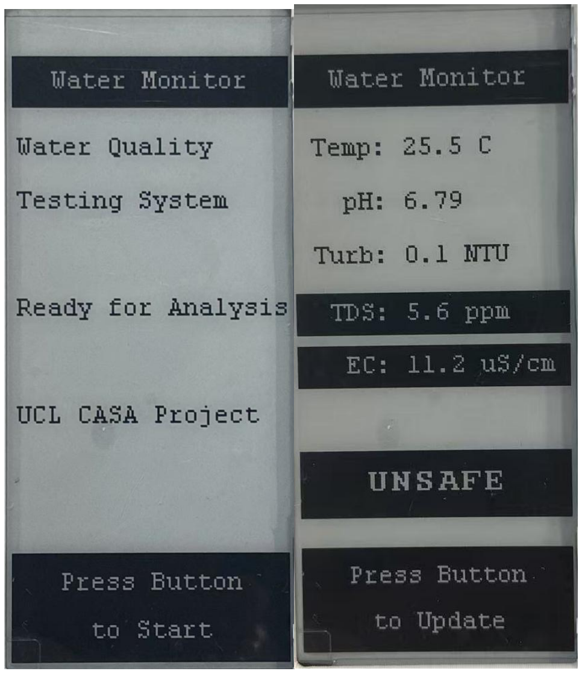
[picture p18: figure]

Figure 12a. Home Screen of the E-paper Display (Left)

Figure 12b. Water Quality Measurement in E-paper Display (Right)

LEDs and Push Button

The tri-colour LED system provides immediate visual feedback using LEDs in three

different colours with resistors to limit current. The LED indication logic is detailed

below:

Red → Unsafe water quality,

Yellow → Marginal water quality,

Green → Excellent water quality.

To achieve power-saving goals, the LEDs only updates when push button is triggered.

This design prevents automatic updates of both the ePaper display and LED indicators,

significantly reducing update frequency to protect the ePaper display's lifespan while

conserving power.

Figure 13 illustrates the complete user interface featuring the tri-colour LED system,

push button, and ePaper display for immediate water quality feedback.

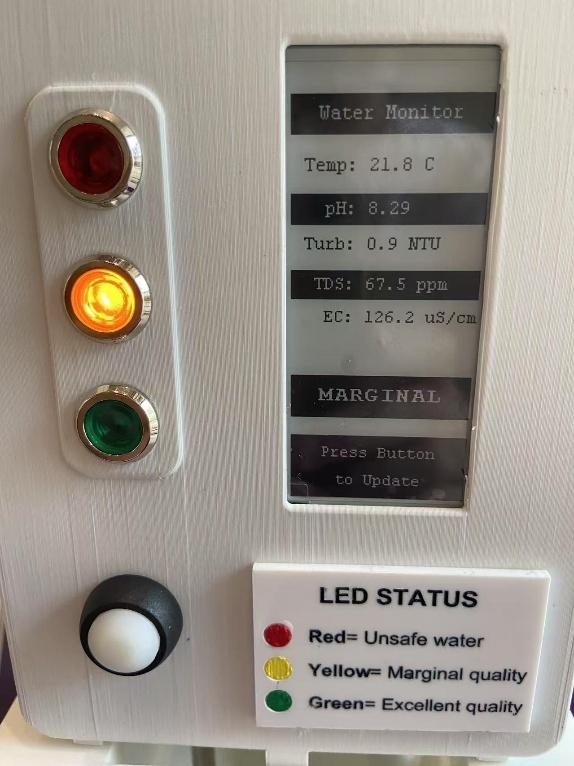
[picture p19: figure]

Figure 13. User Interface Components (LEDs, Button and E-paper)

### 3.4 Enclosure

The enclosure of the portable water quality testing system is fabricated using 3D

printing technology (Figure 14a). It consists of two main components: an upper

housing and a lower protective base. The upper housing contains the MCU, sensor

circuits, and all the remaining electronic components with four holes at its base

designed to accommodate four sensors, allowing them to pass through for direct user

measurements (shown in Figure 14b). The lower section (Figure 14c) serves as a

stable platform to protect the exposed sensor probes. This design enables users to

directly view and identify the four water quality sensors before inserting them into water samples for testing.

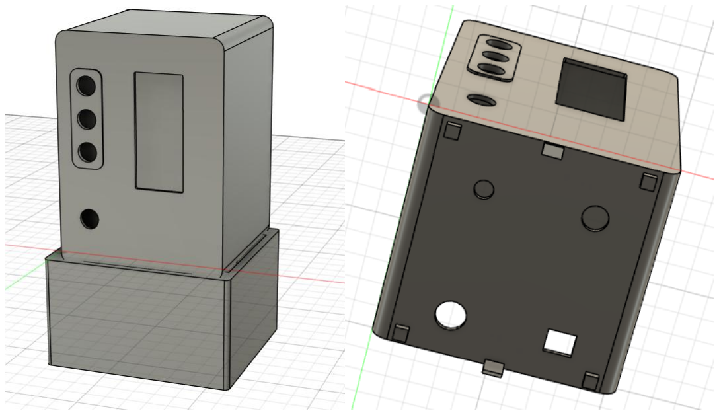
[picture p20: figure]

Figure 14a. 3D Model for Enclosure of the System (top-left)

Figure 14b. 3D Model Four precise openings for sensors (top-right)

Figure 14c. 3D Model for the lower base (bottom)

Although the upper device itself does not require water immersion, the four sensor

openings present a waterproofing challenge potentially. A Rubber Grommets Kit (260

Pcs, 7 Sizes) (Figure 15a) was used to address this issue. These grommets can not only

create effective water seals around each sensor while mechanically securing them in

position (picture is shown in Figure 15b). The design utilises standard 3D printing

materials (PLA) rather than specialized waterproof materials, focusing protection

specifically at sensor penetration points to achieve cost-effectiveness goals while

ensuring the reliable operation. The overall wiring and electronical components in the

box are shown in Figure 16 while the complete physical device is displayed in Figure

17.

Figure 15a. Rubber Grommets Kit (Left)

Figure 15b. Sensors with grommets fixed (Right)

Figure 16 The Wiring in the Box (Left)

Figure 17. Complete Physical Device (Right)

### 3.5 Programming

The water quality monitoring system operates through a carefully designed software

architecture that coordinates sensor data acquisition, user interaction, display

management, and wireless communication.

Sensor Data Acquisition and Processing

The embedded software architecture implements a modular design pattern with separate

modules for sensor management, data processing, and communication handling. The

software framework is built upon the Arduino IDE environment. The sensor data

acquisition is a sequential reading process to minimize electromagnetic interference

between sensors.

Sensor Data code process is shown in Figure 18 below:

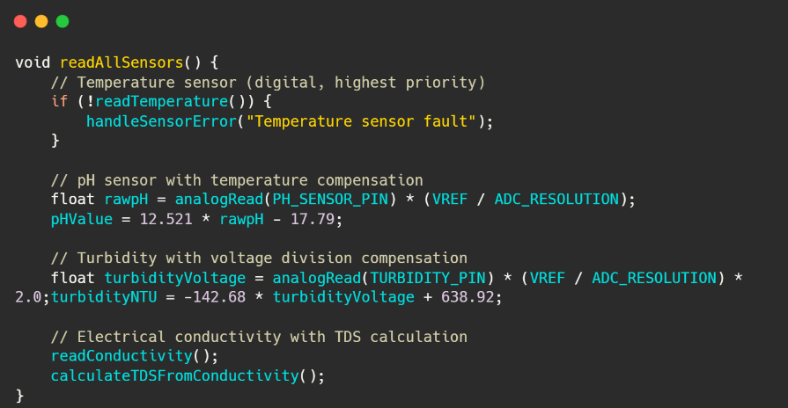
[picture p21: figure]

Figure 18. Code Snippets of Sensors Data Acquisition

Water Quality Classification Algorithm

The water quality assessment is based on comprehensive standards for drinking water

safety of WHO, EPA(World Health Organization, 2017; US EPA, no date). There is

three- classification water quality levels corresponding to the LED indicator colours as

mentioned before: Excellent quality (Green LED) for all optimal ranges for drinking

water, and marginal quality (Yellow LED) for safe to consumption, but one or more

parameters is only in the acceptable ranges while the unsafe quality (Red LED) for at

least one parameter exceeding established safety thresholds, meaning the water is

unsuitable for drinking. The detailed Table 5 shows the water quality assessment

methods for four water quality parameters according to WHO, EPA and the

corresponding code in Figure 19. The measurement result in Arduino IDE serial

monitor is shown in Figure 20.

Table 5. Water Quality Assessment Thresholds
Parameter | Excellent (Green) | Marginal (Yellow) | Unsafe (Red)
pH | 6.5 - 8.0 | 6.0-6.4, 8.1-9.0 | <6.0, >9.0
Turbidity (NTU) | 0 - 1.0 | 1.1 - 4.0 | >4.0
TDS (ppm) | 80 - 300 | 50-79, 301-500 | <50, >500
EC (μS/cm) | 100 - 400 | 50-99, 401-800 | <50, >800

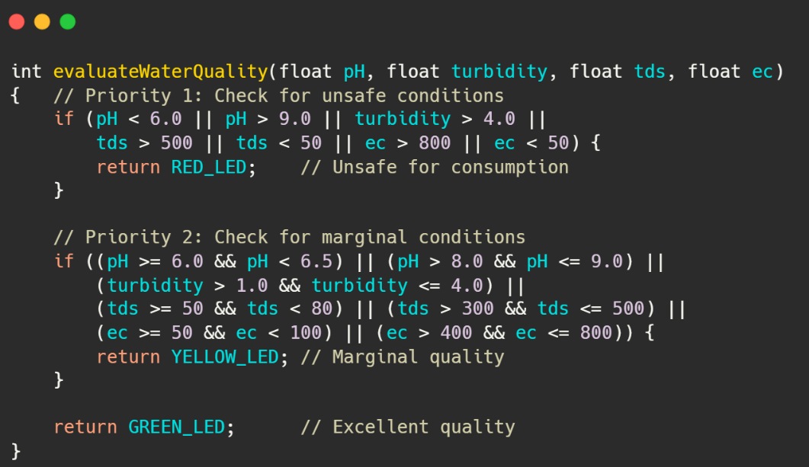
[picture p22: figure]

Figure 19. Code Snippets of Water Quality Evaluation

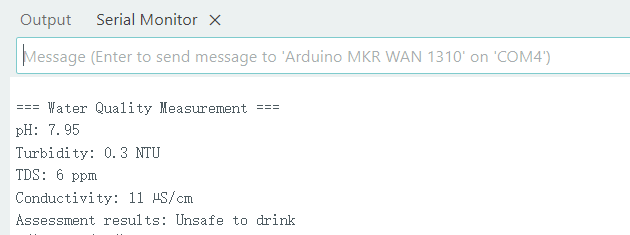
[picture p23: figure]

Figure 20. Water Quality Measurement displayed in Serial Monitor

### 3.6 Communication

The communication part of this system creates a clear and smooth process for data to

move from sensor readings to the final display in both physical and digital forms for

users.

Figure 21 illustrates the complete data flow architecture: The sensors collect water quality data, which moves through LoRaWAN to TTN platform. After that, through

webhook, the sensor data stores into the professional database which will be directly

shown in the web interfaces to users.

Figure 21. Data Flow of the System

LoRaWAN Selection and Configuration

LoRaWAN was selected for this portable water quality monitoring system based on the

testing result across UCL East area for cost-effectiveness and efficiency purpose.

LoRaWAN has advantages when compared with other communication tools, such as

Wi-Fi and cellular. The testing locations span approximately 2km radius, which exceeds

the range of Wi-Fi (50-100m) and would require access to different network credentials

at each facility while LoRaWAN provides 5-15km coverage through The Things

Network's existing gateway infrastructure at UCL East. Besides, unlike cellular

solutions that require high annually subscription fees, LoRaWAN operates in free. The

system only needs to transmit 4 sensor values plus metadata (~20 bytes) per

measurement, which fits well within the data rate capacity. Additionally, the robust

signal of LoRaWAN ensures reliable connectivity in various public spaces, from indoor

facilities to outdoor fountains, making it an ideal communication tool in this research.

The LoRaWAN utilises The Things Network (TTN) to transmit sensor data. There

existing gateway infrastructure in the Marshgate building which can provide reliable

long-range communication for the monitoring applications. The system operates in the

EU868 frequency band to achieve the optimal performance. Each Arduino MKR WAN

1310 board contains a unique DevEUI that must be retrieved before network registration. The code snippet shown below Figure 22 present how to get the DevEUI

in Arduino IDE Serial Monitor.

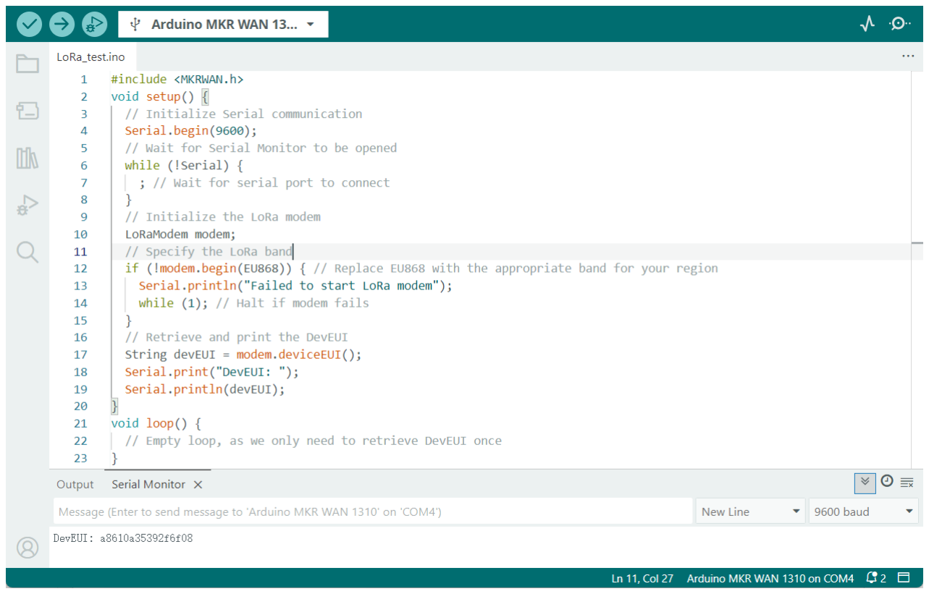
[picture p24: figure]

Figure 22.Code and Serial Monitor output for Retrieving DevEUI

TTN Integration

The TTN requires device registration and payload configuration for data transmission

from the Arduino MKR WAN 1310 to the cloud database. The configuration process

begins with device identification, followed by network registration, payload formatting,

and transmission optimization. The retrieved DevEUI is registered in TTN console

under the water-quality-monitor application, with the system automatically generating

AppKey and AppEUI values for OTAA authentication. The registration process

requires specifying the device name, DevEUI, and selecting the EU868 frequency plan

for European deployment (shown in Figure 23).

The system attempts to connect using the AppEUI and AppKey generated during TTN

device setup. Once authentication succeeds, the device can transmit sensor data to the

network infrastructure with code snippet shown in Figure 24.


Figure 23. End Device Registration

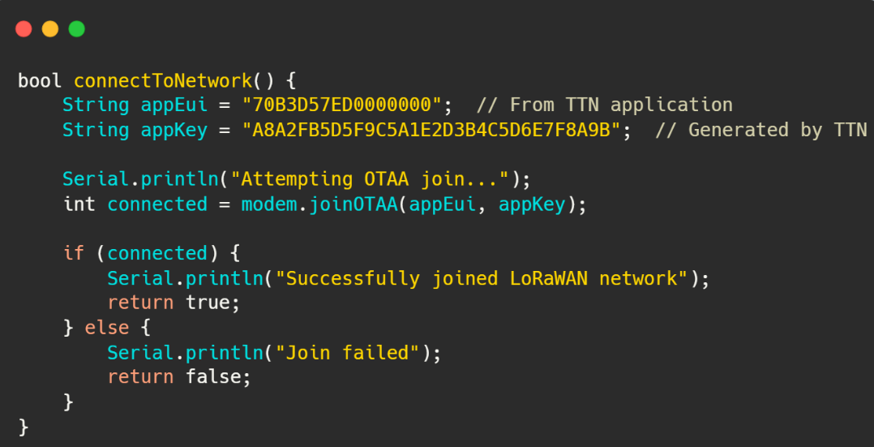
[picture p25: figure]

Figure 24. Code Snippet for Network Join

Payload Formatter Configuration

The sensor data transmitted via LoRaWAN requires conversion from binary format to

human-readable values. A custom JavaScript payload formatter (Figure 25) is

implemented within the TTN application to decode the sensor payload. After the binary

format data is decoded, the TTN payload will display live data message of water quality

parameters that human can understand, which is shown in Figure 26.

Figure 25. JavaScript Payload Formatter (part)

Figure 26 Decoded Payload Live Data Display

Webhook Configuration and Database Integration

The data in TTN can be decoded to the cloud database through HTTP POST requests

by webhook. The webhook configuration specifies the target URL, authentication

headers, and data format requirements (Figure 27). Neon (https://neon.com/) PostgreSQL was chosen as the database and the Vercelserves (https://vercel.com/) as the hosting platform for the webhook API, offering

deployment of Next.js applications.

The webhook connects TTN to the Neon PostgreSQL database through a Vercel-hosted

API endpoint. The webhook is configured with ID "water-quality-webhook" using

JSON format (Figure 28). When TTN receives device transmissions, it automatically

forwards the decoded data to this endpoint for processing and database storage.

The Neon database stores complete sensor measurements with timestamps and the

corresponding water quality status (Figure 29), enabling both real-time monitoring and

historical trend analysis.

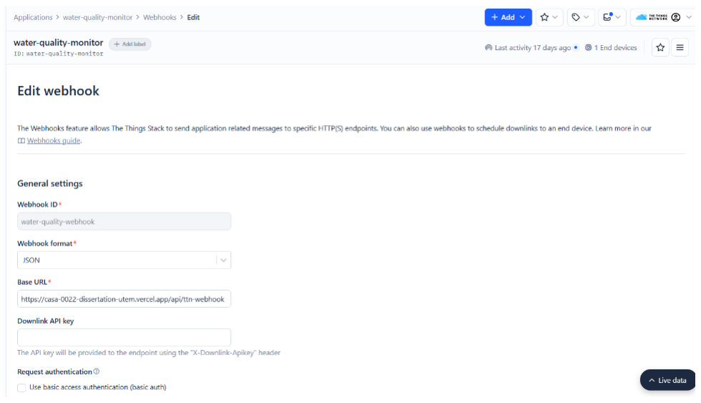
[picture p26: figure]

Figure 27 Create the Webhook

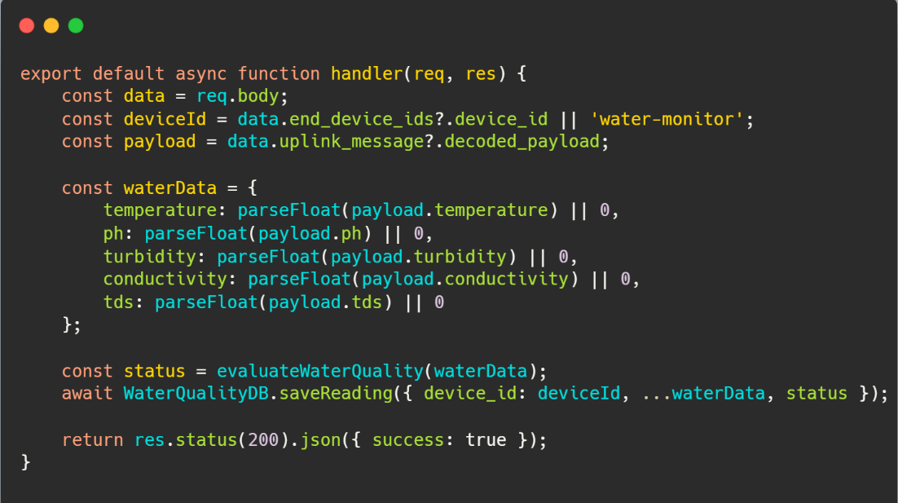
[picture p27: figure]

Figure 28. Code Snippet in JSON Format for Data Storage in DB

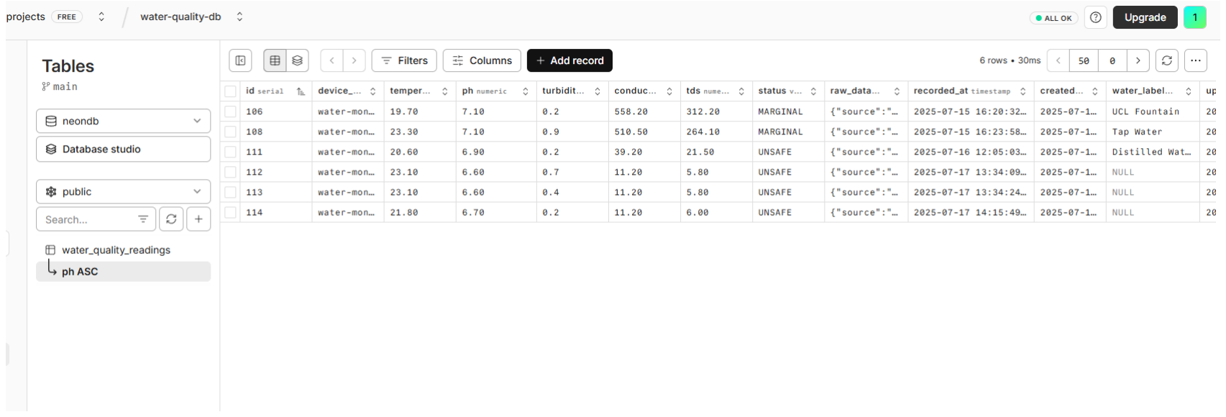
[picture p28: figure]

Figure 29. Screenshot of Neon Water Quality DB Tables

Web Platform Implementation

Following the data storage process described in Section 3.6, a web-based data access

system was developed to present the water quality information stored in the Neon

PostgreSQL database. The platform architecture utilises Next.js framework with

serverless deployment on Vercel (Figure 30), enabling direct database connectivity

through API routes that query the sensor measurements received via TTN webhook

integration. The backend implementation includes data processing functions that

convert raw sensor values into standardized formats and apply the water quality

classification algorithm described in Section 3.5 to generate safety assessments.

Database queries retrieve both real-time measurements and historical records. The

serverless architecture automatically handles scaling requirements while Vercel's

deployment ensures reliable public access.

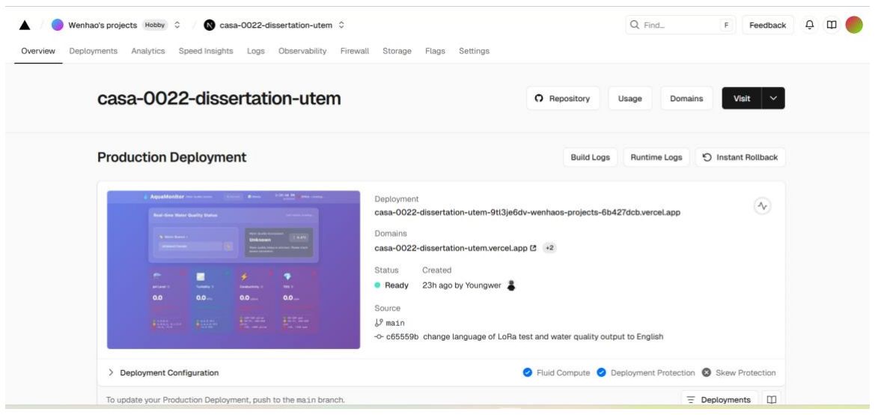
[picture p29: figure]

Figure 30 Screenshot of the Vercel Platform

## 4. Results

This project has three main contributions, with the first two representing the core

scientific contributions: 1.) A validated portable water quality monitoring system

capable of real-time assessment and classification; 2.) A comprehensive dataset of water

quality measurements from diverse sources and public drinking infrastructure around

UCL East Marshgate; 3.) A public web platform that effectively communicates the

research findings to the community, embodying the principles of “Sense, Deploy, and

Communicate” goals in Connected Environments Module.

### 4.1 System Performance and Sensor Validation

The designed IoT water quality monitoring system successfully demonstrated its

capability to measure four key water parameters (pH, turbidity, electrical conductivity,

and temperature) and transmit data through LoRaWAN to TTN gateway. The system

was tested on various water sources in multiple locations near UCL East Marshgate to

validate sensor accuracy and system reliability.

Prior to testing, calibration was performed for sensors requiring linearization to ensure

measurement accuracy. The pH and turbidity sensors were calibrated while the

DS18B20 temperature sensor and EC sensor were used with manufacturer

specifications due to their digital output and inherent calibration. The calibration results

are shown in Table 6.

Table 6. Sensor Calibration and Specification Results

Parameter | Sensor Type | Calibration Status | Calibration Range | Accuracy | R² Value
pH | DFRobot SEN0161 | Calibrated | 4.00 - 10.01 pH | ±0.13 pH | 0.9982
Turbidity | DFRobot SEN0189 | Calibrated | 20 - 500 NTU | ±1.68 NTU | 1*
Temperature | DS18B20 | Manufacturer Spec | -55 to +125°C | ±0.5°C | N/A
EC/TDS | Conductivity Probe | Manufacturer Spec | 0-1000 μS/cm | ±2% reading | N/A

*Note: The turbidity calibration R² = 1.0000 because only two calibration points (20 NTU and 500 NTU) were used.

The pH sensor demonstrated excellent linearity with R² = 0.9982(as shown in Figure),

confirming the reliability of the derived calibration equation: pH = 12.521 × Voltage -

17.79. The turbidity sensor required voltage division using two 6.4kΩ resistors to

prevent ADC damage, achieving stable readings with the linear relationship: NTU = -

142.68 × Voltage + 638.92. The DS18B20 temperature sensor provided direct digital

readings with factory calibration, eliminating the need for additional calibration

procedures. Similarly, the electrical conductivity sensor was used with manufacturer

specifications, with TDS values calculated using the standard conversion factor: TDS

(ppm) = EC (μS/cm) × 0.65.

### 4.2 Water Source Testing and Classification Results

The device demonstrated immediate response to different water quality conditions, with

the tri-colour LED system providing instant visual feedback and e-paper display

updating detailed parameter readings within 3 - 5 seconds of sensor immersion. Figure

25 shows the system's real-time performance during testing of different water sources.

### 4.2.1 Real-time Device Performance and Classification

The device demonstrated immediate response to different water quality conditions, with

the tri-colour LED system providing instant visual feedback and e-paper display

updating detailed parameter readings within 3-5 seconds of sensor immersion. Figure

31 shows the system's real-time performance during testing of different water sources.

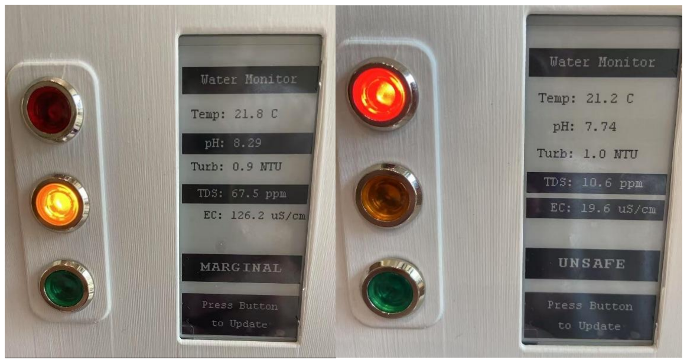
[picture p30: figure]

Figure 31. Device Testing Results

Bottled water(top-left) - UCL Fountains Water(top-right)

UCL Tap Water(bottom-left) – Distilled Water(bottom-right)

Bottled water from the supermarket test shows Green LED illuminated with Excellent

water quality. UCL Water Fountain and tap water tests both show Yellow LED

illuminated with Marginal water quality while the distilled water test showing Red

LED, meaning UNSAFE water quality due to the low TDS and EC values (lack of

minerals in water).

The physical system run smoothly with push-button activation system and the LED

classification proved highly effective. Users are able to obtain immediate water quality

assessments by simply immersing the sensors and pressing the measurement button

performed consistently, correctly identifying water safety levels according to the

established WHO/EPA thresholds across all test scenarios.

Following extensive field testing across different water sources, comprehensive data

was collected to validate the system's classification accuracy. Each water source was

tested multiple times (ranging from 4 to 15 measurements per source) depending on

accessibility and availability. The complete dataset (Table 8) demonstrates the device's

ability to discriminate between water quality levels effectively.

Table 7. Comprehensive Water Quality Measurements and Classifications (Average values from multiple tests)

Water Source | pH | Turbidity
| | (NTU)

TDS

(ppm)

EC

(μS/cm)

Temp

(°C)

Water

Status

Test

Count

UCL Water Fountains | 7.4 | 0.6 | 187 | 287 | 21.8 | Excellent | 15
Brita Filtered | 7.2 | 0.3 | 124 | 191 | 21.3 | Excellent | 12
Volvic Bottled | 7.6 | 0.1 | 95 | 146 | 21.1 | Excellent | 6
Distilled Water | 6.9 | 0.1 | 12 | 18 | 21.1 | Unsafe | 10
Tap water | 8.2 | 0.8 | 342 | 526 | 19.4 | Marginal | 8
Rainwater | 6.3 | 2.1 | 23 | 35 | 18.9 | Unsafe | 4

The system can successfully differentiate between water sources. Testing the same

source multiple times showed consistent results, with parameter variations under 5%,

confirming the sensor system’s reliability and repeatability.

### 4.3 Public Space Water Quality Assessment

The portable feature of the system makes it possible to test across diverse public

drinking facilities in the UCL East Marshgate area, which allows for comparative

analysis of water quality across different types of public infrastructure and usage

environments. The areas near London Olympic Park were selected to test different

categories of public water infrastructure. Figure 32 illustrates the geographical

distribution of testing sites, spanning from UCL East Campus facilities including water

fountain (Figure 33) and bathroom tap (Figure 34), to major public venues including

the Olympic Park (Figure 35) and Westfield shopping Ave (Figure 36). Table 8 presents

the complete dataset from the multi-location assessment.

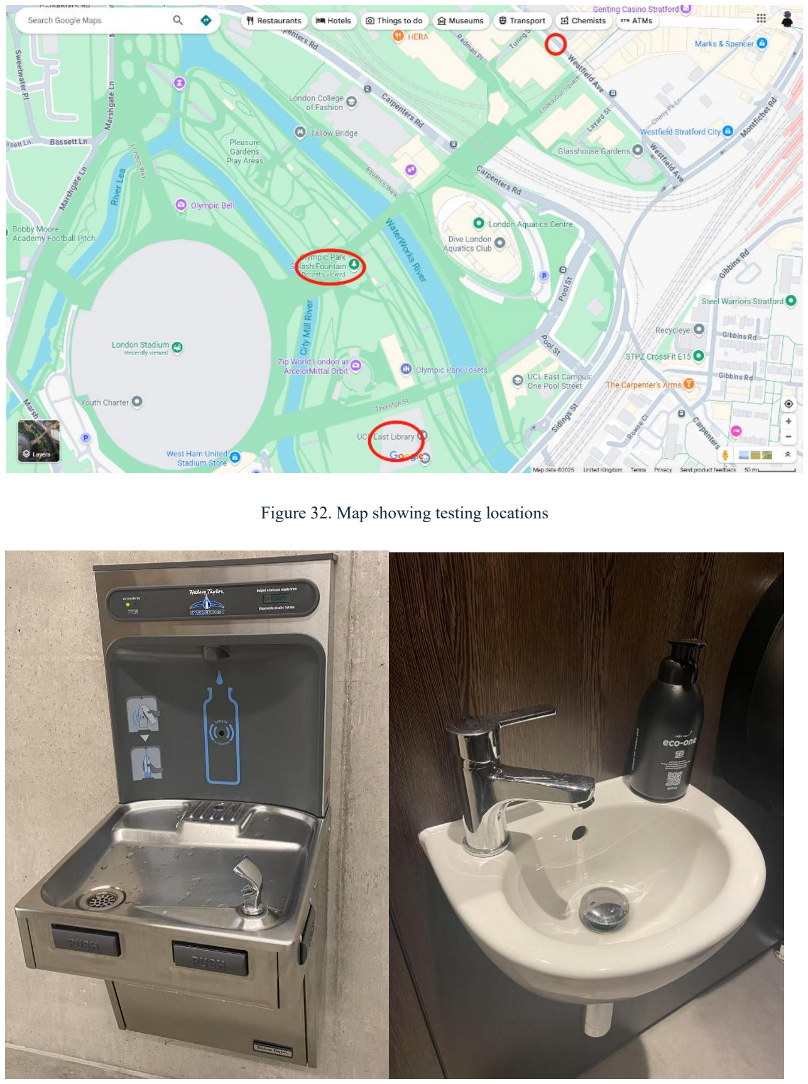
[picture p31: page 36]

Figure 32. Map showing testing locations

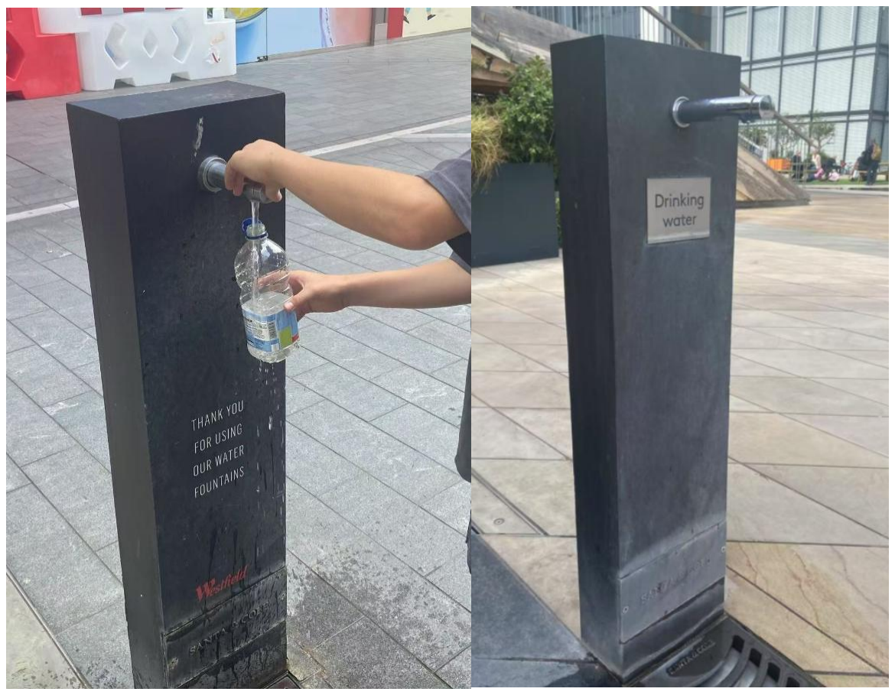
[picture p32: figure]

Figure 33. Water Source 1: UCL Marshgate Water Fountain (Top-Left)

Figure 34. Water Source 2: Marshgate Bathroom Tap (Top-Right)

Figure 35. Water Source 3: Westfield Water Fountains (Bottom-Left)

Figure 36. Water Source 4: Water Fountains in the Queen Elizabeth Olympic Park (Bottom-Right)

Table 8. Public Space Water Quality Assessment Results

Specific Site | pH | Turbidity (NTU) | TDS (ppm) | EC (μS/cm) | Temp (°C) | Classification
Marshgate Water Fountain | 7.3 | 0.8 | 176 | 271 | 21.5 | Excellent
Marshgate Washroom Tap | 7.4 | 0.6 | 187 | 287 | 21.8 | Excellent
Olympic Park Plaza Fountain | 7.6 | 1.2 | 203 | 312 | 20.3 | Excellent
Westfield Ave Public Fountain | 7.2 | 1.8 | 245 | 377 | 22.1 | Excellent

### 4.3 Web-based Data Visualization Platform for Public Access

A Next.js web application was developed for remote monitoring of water quality data on both desktop and mobile devices. Unlike traditional laboratory-based testing that

provides delayed results to authorities only, the web platform is publicly accessible via

Vercel hosting, enabling users to monitor water quality measurements and historical

trends from any location. On the homepage, users can view real-time water quality

status with coloured background and access detailed parameter readings including pH,

turbidity, TDS, and temperature measurements (Figure 37). It uses the same three-level

system as the embedded device: green for excellent quality, yellow for acceptable

conditions, and red for unsafe water. Historical data is shown in a structured table

(Figure 38), listing past measurements with timestamps, quality ratings, and data source

details, allowing users to track water quality trends and spot patterns over time. The

water source tracking feature allows users to categorize and compare measurements

from various public infrastructure types, directly supporting the core research finding

that different facility categories exhibit distinct water quality characteristics. Users can

choose from predefined water sources (e.g., tap, river, lake, well) or input a custom

source name via a dropdown menu and text field in the interface (Figure 39).

Figure 37. Web Application Screenshot

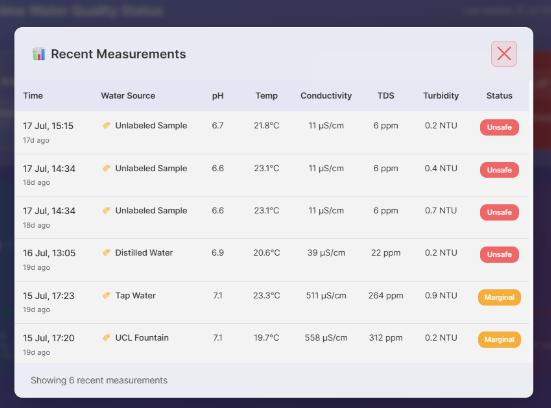
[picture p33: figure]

Figure 38. Historical Records Table

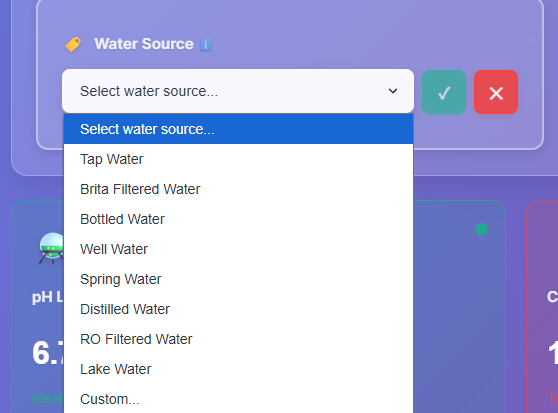
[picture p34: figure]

Figure 39. Water Source Tracking and Record

## 5. Discussion

### 5.1 Observations and Key Findings Analysis

The experimental results demonstrate that the portable water quality monitoring system

successfully achieved its primary objectives of providing immediate water quality

assessment through both physical and digital user interfaces. There are some key

findings:

1) The most significant finding of this research is the water quality variations detected

across different types of public drinking infrastructure in the UCL East area. The results

revealed small but consistent differences in water quality between facility types.

University campus water sources averaged 182 ppm TDS, while fountains in shopping

centre and park averaged 245 ppm TDS, representing a 35% difference in mineral

content between educational and commercial infrastructure networks. Furthermore, it

was observed that spatial variability exists even within the same infrastructure type.

Municipal tap water measurements showing an 83% inconsistence in TDS levels

(shown in Table 7 and 8) between different sources (ranging from 187 ppm at

Marshgate Washroom Tap to 342 ppm in general tap water samples from other locations)

This finding demonstrates that public drinking facilities are not uniform in water quality

at UCL East area and exhibit complex water quality patterns across different locations.

2) The system demonstrated comprehensive water safety assessment beyond traditional

contamination detection. Notably the system classified both distilled water and

rainwater as "Unsafe" due to extremely low mineral content (12 ppm TDS and 23 ppm

TDS respectively) which is consistent with the WHO guidelines that adequate mineral

content in drinking water is essential for optimal health(World Health Organization,

2017). While neither of water is not harmful in short-term for people, the World Health

Organization notes that prolonged consumption of demineralized water may lead to

mineral deficiencies and electrolyte imbalances, particularly affecting calcium and

magnesium levels(Nutrients in drinking water, 2005; Kozisek, 2024). Additionally, the

rainwater sample additionally exhibited slightly acidic conditions (pH 6.3) and turbidity

(2.1 NTU). It is in unsafe classification due to potential atmospheric contaminants and

surface collection impurities. This classification demonstrates the system’s ability to

detect both over-contamination and under-mineralization scenarios, representing a

more holistic approach to water safety than conventional monitoring systems that

primarily focus on contaminant detection.

3) Across all tested water sources, the system demonstrated consistent water quality

classification classifies the drinking water quality according to WHO/EPA standards

(Excellent/Marginal/Unsafe). The system successfully differentiated between high-

quality sources (bottled water, filtered water) standard municipal supplies (tap water,

fountain water), and problematic sources (distilled water, rainwater) in accordance with

established standards although the laboratory-based validation work was not conducted as part of the study, which remains a future work. The LoRaWAN communication

infrastructure proved reliable and achieved consistent data transmission across all

testing locations within the UCL East area, suggesting that existing TTN gateway

infrastructure provides reliable coverage for portable monitoring applications.

### 5.2 Limitations and Reflections

From both technical performance and practical deployment perspectives, several

significant limitations emerged that require honest acknowledgment and critical

analysis.

1) The large size is one of the device’s main limitations, measuring 15cm ×

10cm × 8cm and weighing 450g, making it too bulky for pocket-sized use.

Because of the four water quality sensors, especially the 12cm-long pH

probe and the 8cm × 5cm turbidity sensor housing, it requires a bigger

enclosure for proper placement and circuitry. This conflicts with the

"lightweight and compact" benefits claimed by Zainurin et al. (2022) for

portable systems, showing a trade-off between including multiple sensors

and keeping the device portable.

2) The USB power requirement presents a significant limitation for true

portable deployment. While USB power ensures reliable measurements

during testing, it restricts the system's ability to operate independently in

locations without power sources. The current device requires USB power

sources to work, which is conflicts with the autonomous operation

capabilities highlighted by Demetillo, Japitana and Taboada (2019) for

remote monitoring applications. It has not achieved the portable purpose

that “true portability should be able to be distributed to public facility

without any dependencies on infrastructure”.

3) Despite eliminating TDS/EC sensor interference through design

modifications, the system still requires periodic recalibration to maintain

accuracy, particularly for pH and turbidity sensors. This maintenance

requirement contradicts the "plug-and-play" installation advantages

promoted in the literature and represents a practical barrier to widespread

deployment in public spaces where technical maintenance access may be

limited.

### 5.3 Future Work

From the limitation and reflection mentioned in Section 5.2, some future works emerge

from the analysis: 1) Investigation of miniaturized sensor alternatives or sensor

multiplexing approaches to reduce device footprint while maintaining measurement

comprehensiveness; 2) Implementation of battery-powered operation with integrated

power management systems, including deep sleep functionality and potentially solar

charging capabilities, to enable autonomous deployment without infrastructure

dependencies; 3) Integration of automated calibration verification systems to reduce

manual maintenance requirements and ensure sustained accuracy in unsupervised

deployments.

## 6.Conclusion

In response to the research questions posed, this study successfully demonstrates that a

portable, low-cost drinking water monitoring device can effectively provide immediate

water quality safety information to the public, while an interactive web platform can

deliver real-time data visualization and historical trend analysis for enhanced public

awareness. This research makes three principal contributions to the field of IoT-based

water quality monitoring. First, the study addresses critical sensor interference

challenges through innovative design modifications, eliminating TDS/EC sensor cross-

talk while achieving exceptional calibration accuracy (R² = 0.9982 for pH) that

surpasses many existing portable systems. Second, the integrated system demonstrated

high accuracy classification of drinking water quality according to WHO/EPA standards

across diverse public drinking facilities, with real-time assessment capabilities that

significantly outperform traditional laboratory-based approaches requiring hours or

days for results. Third, the research establishes a comprehensive IoT infrastructure

successfully integrating LoRaWAN communication, multi-level user feedback system

(LED indicators, e-paper display, and web dashboard), and cloud-based data storage,

enabling public health monitoring that achieved data transmission across all tested

locations within the UCL East area where the LoRaWAN network is covered. The

successful testing across varied public infrastructure types, from campus to major

commercial venues, validates the system's practical viability for widespread public

space implementation.

## Bibliography

Badger Meter (2023) Remote Water Quality Monitoring: Where We Are and How We Got Here. Badger Meter. Available at: https://www.badgermeter.com/en-gb/blog/remote-water-quality-monitoring-evolution/.

Bichelman, J. (2024) ‘Drinking Fountains Contain 50,000x More Bacteria Than Toilet
Seats, | Study | Finds’, | Green | Matters, | 8 | January. | Available | at:
https://www.greenmatters.com/health-and-wellness/are-water-fountains-clean.

Dabrowska, A. et al. (2024) ‘Expanding access to water quality monitoring with the open-source WaterScope testing platform’, npj Clean Water, 7(1), p. 68. Available at: https://doi.org/10.1038/s41545-024-00357-y.

Demetillo, A.T., Japitana, M.V. and Taboada, E.B. (2019) ‘A system for monitoring water quality in a large aquatic area using wireless sensor network technology’, Sustainable Environment Research, 29(1), p. 12. Available at: https://doi.org/10.1186/s42834-019-0009-4.

Drinking Water Inspectorate (2024) Drinking Water 2023: A Report by the Chief Inspector. Drinking Water Inspectorate.

Environmental Measurement Systems (2014) ‘Fondriest’, Conductivity, Salinity & Total Dissolved Solids, 3 March. Available at: https://www.fondriest.com/environmental-measurements/parameters/water-quality/conductivity-salinity-tds/.

Fields, Z. (no date) IoT in Water Management with Smart Water Quality Monitors. Blues Wireless.

Hilary Kelechi, A. et al. (2021) ‘Design and Implementation of a Low-Cost Portable Water Quality Monitoring System’, Computers, Materials & Continua, 69(2), pp. 2405–2424. Available at: https://doi.org/10.32604/cmc.2021.018686.

Hossain, S. et al. (2020) ‘Spectrophotometric Online Detection of Drinking Water Disinfectant: A Machine Learning Approach’, Sensors, 20(22), p. 6671. Available at: https://doi.org/10.3390/s20226671.

Jabbar, W.A. et al. (2024) ‘Development of LoRaWAN-based IoT system for water quality monitoring in rural areas’, Expert Systems with Applications, 242, p. 122862. Available at: https://doi.org/10.1016/j.eswa.2023.122862.

Jiang, X. and Meng, Q. (2015) ‘Design of Optical Fiber SPR Sensing System for Water Quality Monitoring’:, in. 2015 International Conference on Computational Science and Engineering, Qingdao, China. Available at: https://doi.org/10.2991/iccse-15.2015.21.

Kozisek, F. (2024) ‘12. HEALTH RISKS FROM DRINKING’. Available at: https://www.researchgate.net/publication/252043662_Health_Risk_from_Drinking_Demineralized_Water.

Liu, Y.-T. et al. (2018) ‘A solar powered long range real-time water quality monitoring system by LoRaWAN’, in 2018 27th Wireless and Optical Communication Conference

(WOCC). 2018 27th Wireless and Optical Communication Conference (WOCC), Hualien: IEEE, pp. 1–2. Available at: https://doi.org/10.1109/WOCC.2018.8373792.

Miao, H.-Y. et al. (2022) ‘On Construction of a Campus Outdoor Air and Water Quality Monitoring System Using LoRaWAN’, Applied Sciences, 12(10), p. 5018. Available at: https://doi.org/10.3390/app12105018.

NASA (2023) ‘ARSET - Monitoring Water Quality of Inland Lakes using Remote Sensing’,
NASA. | Available | at: | https://appliedsciences.nasa.gov/get-
involved/training/english/arset-monitoring-water-quality-inland-lakes-using-remote-sensing.

Nutrients in drinking water (2005). Geneva, Switzerland: Water, Sanitation, and Health Protection and the Human Environment, World Health Organization. Available at: https://iris.who.int/bitstream/handle/10665/43403/9241593989_eng.pdf.

Pires, L.M. and Gomes, J. (2024) ‘River Water Quality Monitoring Using LoRa-Based IoT’, Designs, 8(6), p. 127. Available at: https://doi.org/10.3390/designs8060127.

The Guardian (2018) ‘How to drink from a water fountain – without catching something’, 23 January.

The Guardian (2025) ‘Revealed: drinking water sources in England polluted with forever chemicals’, 16 January.

Thomas, O., Delpla, I. and Thomas, M.-F. (2017) ‘Drinking Water’, in UV-Visible Spectrophotometry of Water and Wastewater. Elsevier, pp. 261–280. Available at: https://doi.org/10.1016/B978-0-444-63897-7.00008-1.

US EPA (no date) National Primary Drinking Water Regulations. Available at: https://www.epa.gov/ground-water-and-drinking-water/national-primary-drinking-water-regulations.

Vernier (2019) ‘Will I get interference when I put two sensors in the same solution?’, 5 July. Available at: https://www.vernier.com/til/638.

Vijayakumar, N. and Ramya, R. (2015) ‘The real time monitoring of water quality in IoT environment’, in 2015 International Conference on Innovations in Information, Embedded and Communication Systems (ICIIECS). 2015 International Conference on Innovations in Information,Embedded and Communication Systems (ICIIECS),
Coimbatore, | India: | IEEE, | pp. | 1–5. | Available | at:
https://doi.org/10.1109/ICIIECS.2015.7193080.

World Health Organization (2017) Guidelines for drinking-water quality: fourth edition incorporating first addendum. 4th ed., 1st add. Geneva: World Health Organization. Available at: https://iris.who.int/handle/10665/254637 (Accessed: 3 August 2025).

Yang, H. et al. (2022) ‘A Review of Remote Sensing for Water Quality Retrieval: Progress
and | Challenges’, | Remote | Sensing, | 14(8), | p. | 1770. | Available | at:
https://doi.org/10.3390/rs14081770.

Zainurin, S.N. et al. (2022) ‘Advancements in Monitoring Water Quality Based on Various Sensing Methods: A Systematic Review’, International Journal of Environmental
Research | and | Public | Health, | 19(21), | p. | 14080. | Available | at:
https://doi.org/10.3390/ijerph192114080.

## Appendix A

Bill of Materials and Components

MCU, Sensors and Calibration Solutions Parts

DS18B20 Temperature Sensor Module Kit (Waterproof) | 12.59
Water Conductivity Sensor | 10.23
Turbidity Sensor Module | 18.49
pH Sensor Module | 25.99
pH Calibration Solution and Buffer (pH 4.0, 7.0, 10.01) | 16.79
Turbidity Solution (20 NTU 500 NTU) | 15.69
MKR1310 | 40.00

Visualisation and Customised Components

LED Lights | 7.99
2.9inch E-paper Module | 21.19
Waterproof Momentary Push Button | 5.99
Rubber Grommets Kit (260 Pcs, 7 Sizes) | 15.00
Total | 189.95

The table showed above is based on the price in Aug 2025.

*Over 70% of the cost is the MCU, Sensors and Calibration Solutions part.

## AI Use Acknowledgement

I acknowledge the use of Claude (Claude Sonnet 4, https://claude.ai) as an assistive tool

in accordance with UCL's Category 2 guidelines. Specifically:

1. To receive structural suggestions for some part of the dissertation.

Prompts used: My dissertation is a portable water quality testing device using multiple

water parameters sensor, present the initial outline of the of the dissertation.

2. To ensure grammar and style consistency.

Prompts used: Check the grammar of the dissertation and correct the wrong ones, and

some sentences with unclear expression.

All content, analysis, and ideas presented are my own, and AI was used solely as a

supportive resource, not to generate original ideas or replace my own work.

Wenhao Yang

2025/8/22

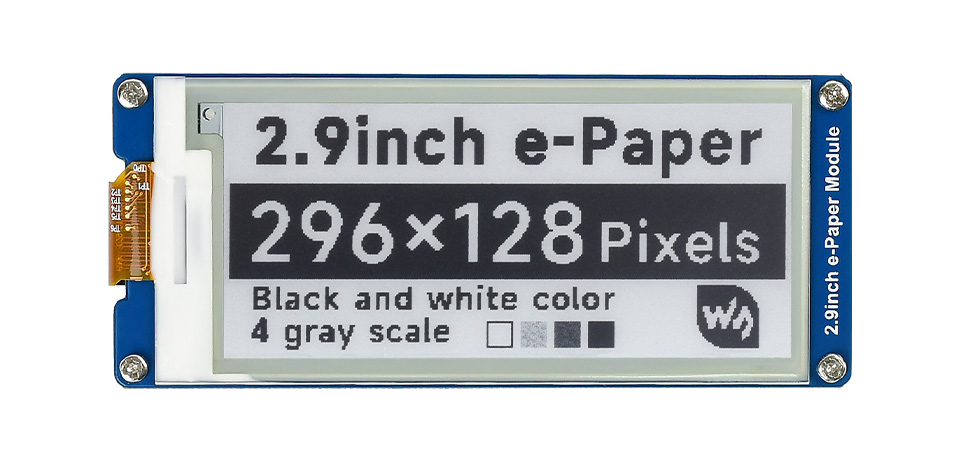
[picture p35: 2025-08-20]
image/2.9inch-e-Paper-Module-details-1.jpg

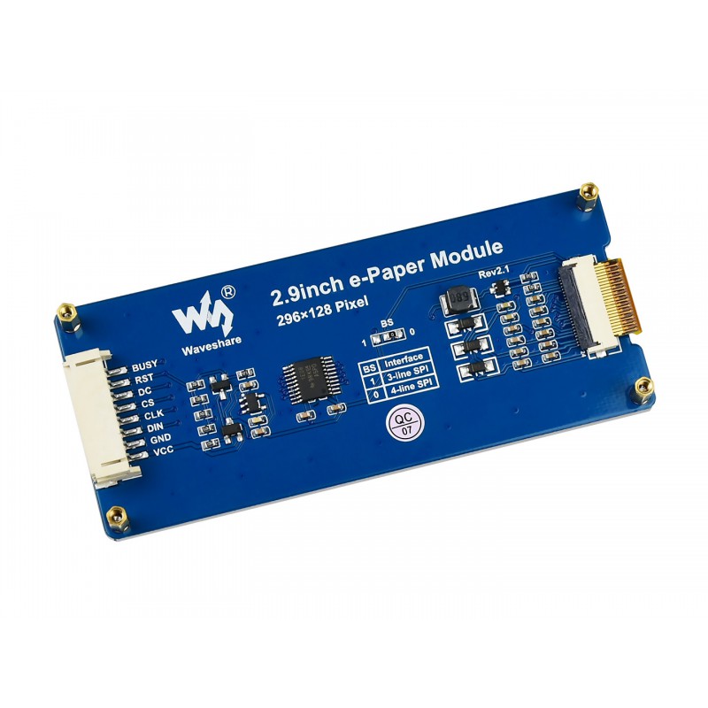
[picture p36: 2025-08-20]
image/2.9inch-e-paper-module-2_4.jpg

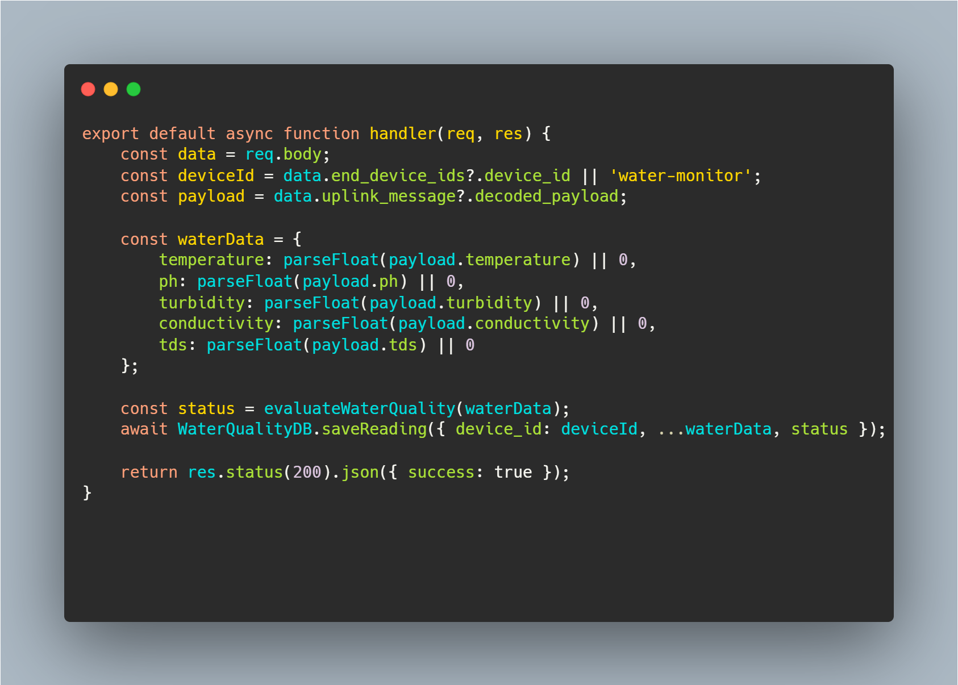
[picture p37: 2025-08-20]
image/code/webhook jason.png

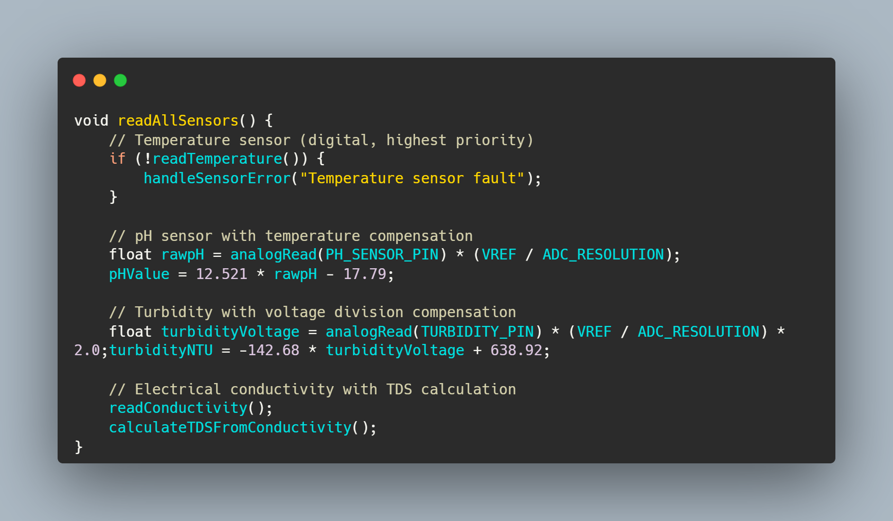
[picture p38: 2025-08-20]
image/code/readAllSensors.png

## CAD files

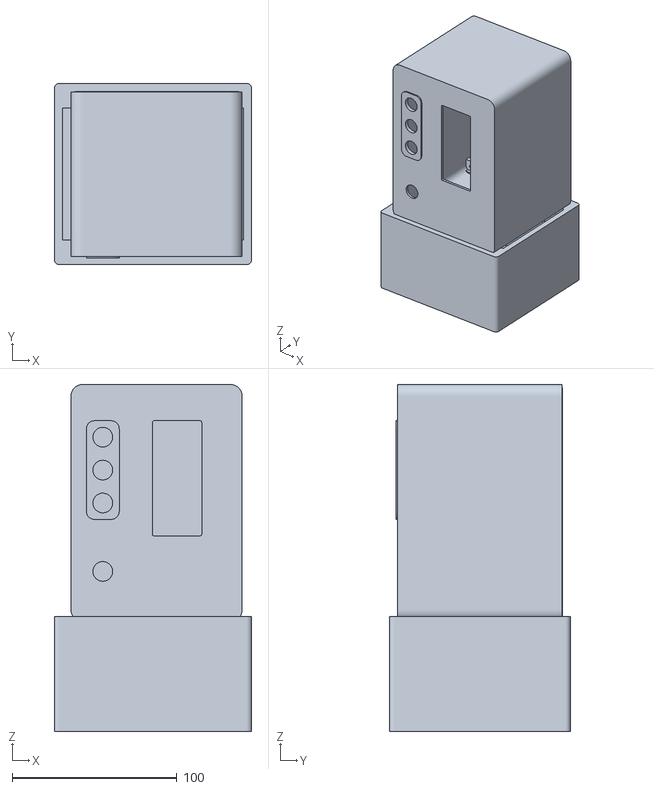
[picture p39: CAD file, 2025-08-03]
enclosure.stl
120.0 x 110.0 x 210.9

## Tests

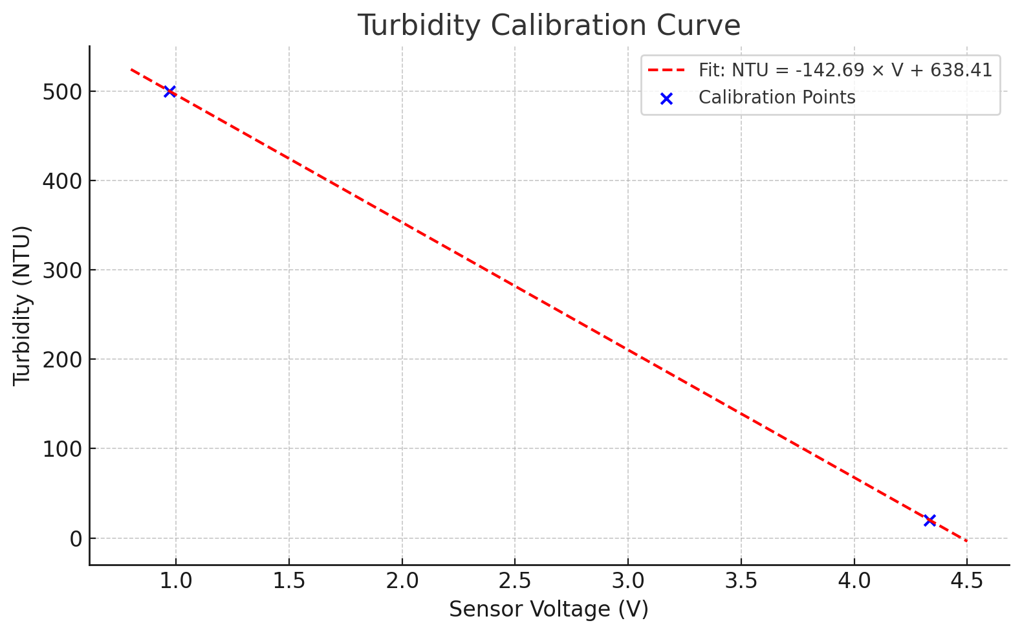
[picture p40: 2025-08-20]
image/Turbidity-calibration-graph.jpg

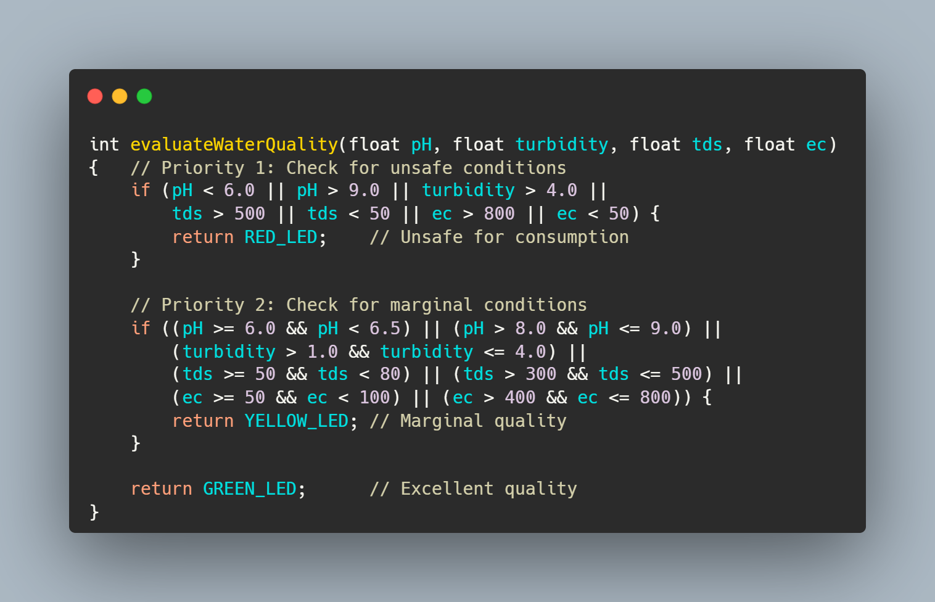
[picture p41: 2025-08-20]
image/code/evaluateWaterQuality.png

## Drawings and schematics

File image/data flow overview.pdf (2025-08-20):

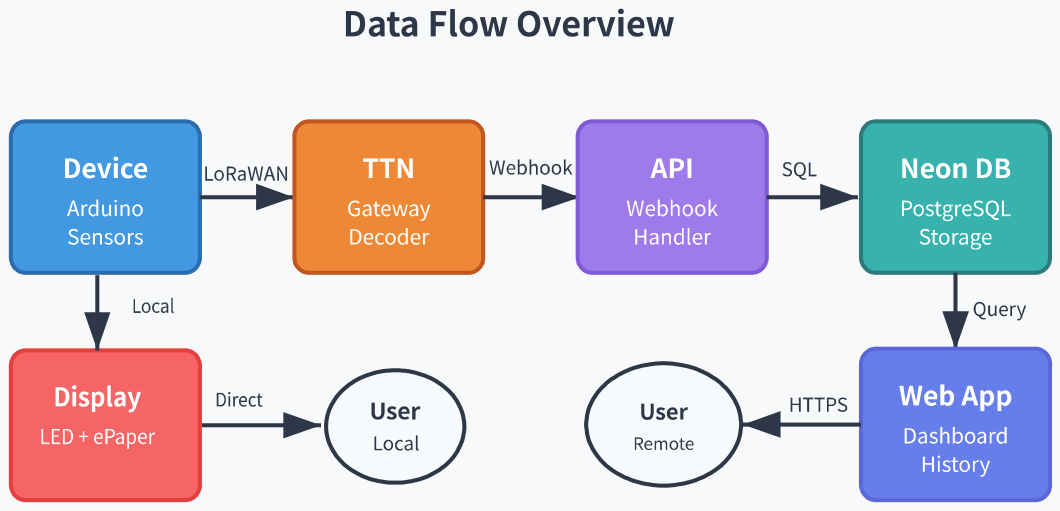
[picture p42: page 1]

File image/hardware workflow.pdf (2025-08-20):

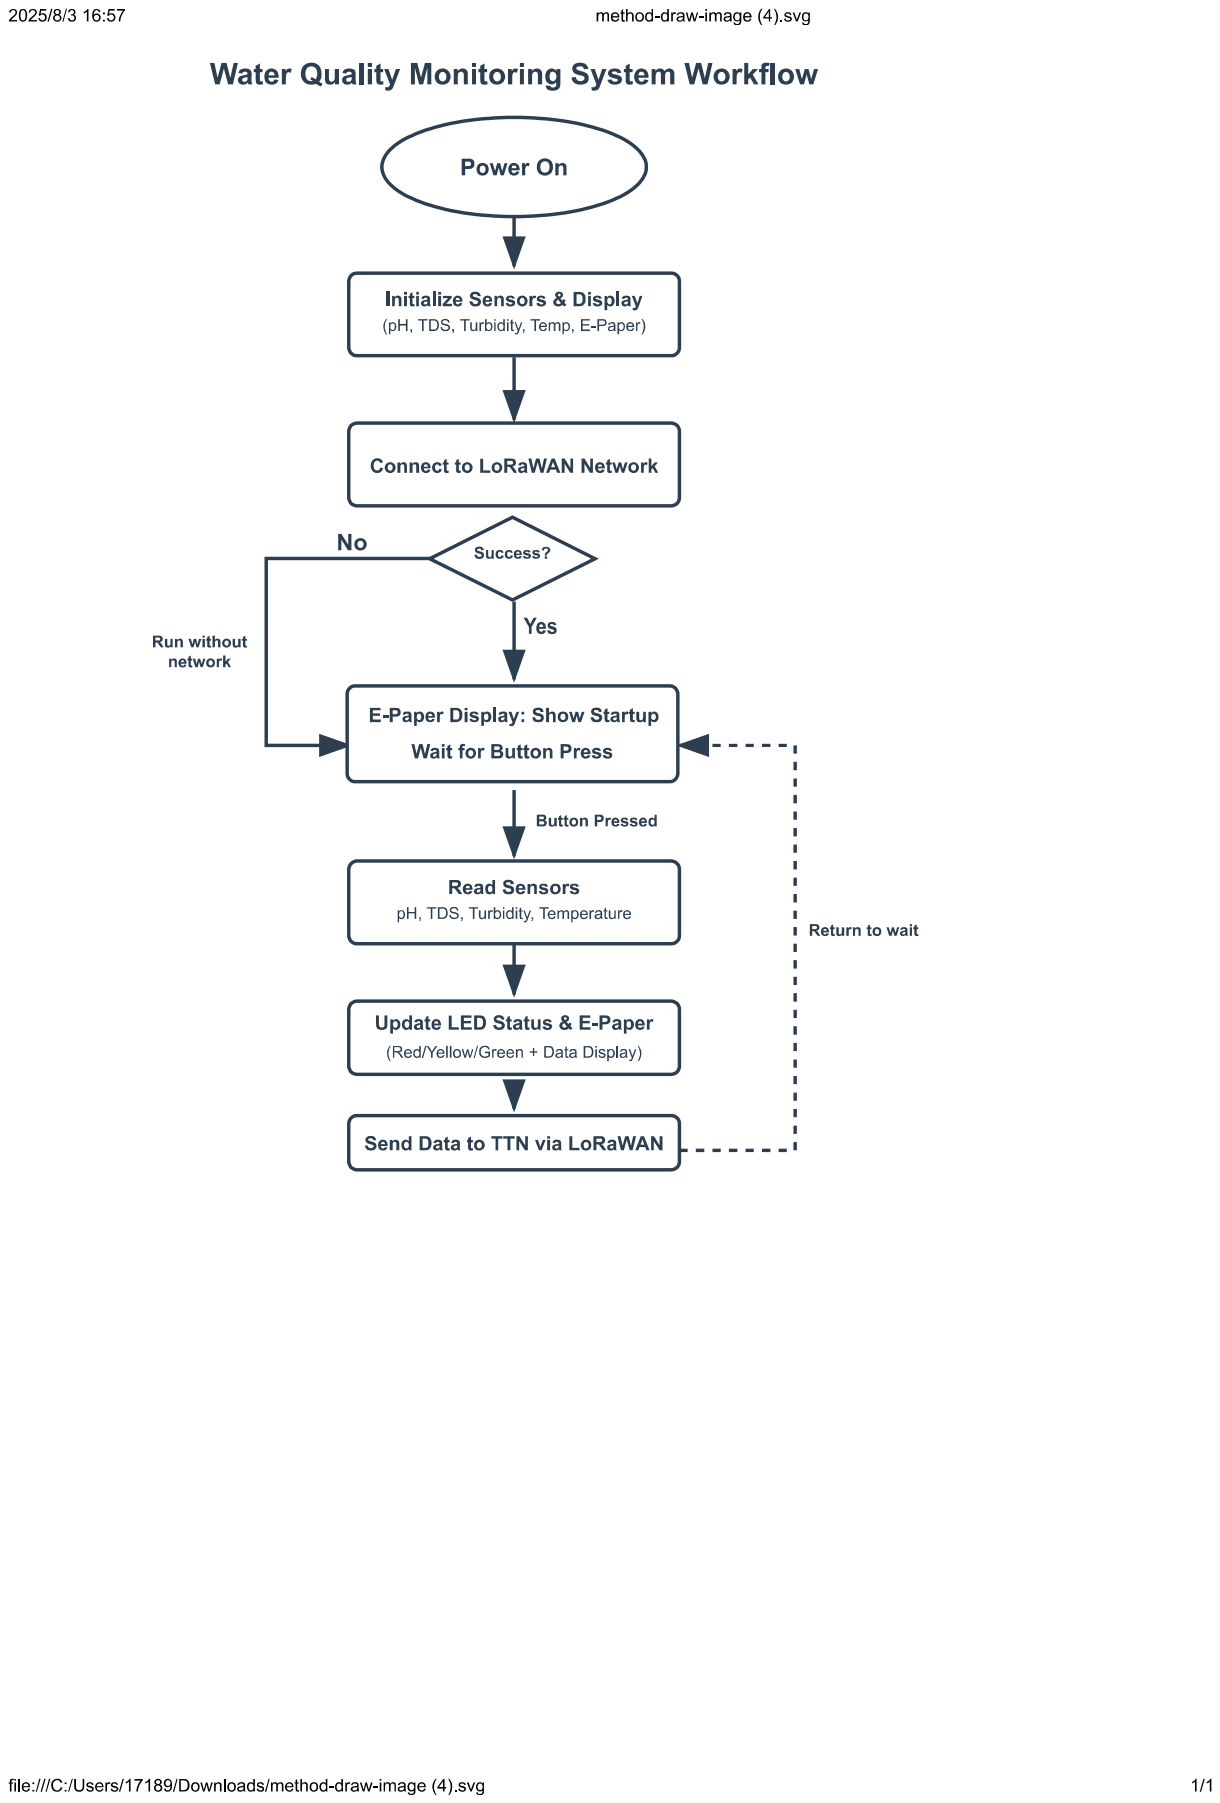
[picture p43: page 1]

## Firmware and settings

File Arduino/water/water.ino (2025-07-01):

// ==================== 文件3：Arduino/water/water.ino ====================
/**
 * water.ino - 水质监测系统主程序 (禁用LoRA自动发送版)
 * 
 * 包含LED三色指示水质状态功能
 */

#include "WaterMonitor.h"

void setup() {
  Serial.begin(115200);
  
  // 等待串口
  unsigned long startTime = millis();
  while (!Serial && millis() - startTime < 5000) {
    ;
  }
  
  Serial.println("\n=================================");
  Serial.println("   水质监测系统 v2.3 (手动版)     ");
  Serial.println("=================================");
  
  // 初始化系统
  initializeSimpleSystem();
  
  Serial.println("\n系统启动完成!");
  Serial.println("按下按钮开始水质检测");
  Serial.println("LED指示: 绿灯=优秀 黄灯=一般 红灯=不安全");
  Serial.println("⚠️  LoRa自动发送已禁用，仅手动触发");
  Serial.println("---------------------------------");
}

void loop() {
  // 处理按钮输入
  handleButtonInput();
  
  // 只处理LoRa接收消息，不自动发送
  if (loraConnected) {
    handleLoRaReceiveOnly();  // 使用新的只接收函数
  }
  
  // 处理简单串口命令
  handleSimpleSerialCommands();
  
  // 禁用自动发送检查
  // checkAutoSend();  // 注释掉这行
  
  delay(100);
}

// ==================== 简化的系统初始化 ====================
void initializeSimpleSystem() {
  Serial.println("开始系统初始化...");
  
  // 1. 初始化传感器（包含LED初始化）
  initializeSensors();
  delay(1000);
  
  // 2. 初始化E-Paper显示
  initializeEPaper();
  delay(1000);
  
  // 3. 初始化按钮控制
  initializeButton();
  delay(500);
  
  // 4. 尝试初始化LoRa（不强制要求成功）
  Serial.println("尝试初始化LoRa...");
  if (initializeLoRa() && connectToNetwork()) {
    Serial.println("✓ LoRa初始化成功!");
    Serial.println("⚠️  自动发送已禁用，只能手动发送");
  } else {
    Serial.println("⚠ LoRa初始化失败，系统在离线模式下运行");
  }
  
  // 5. 显示启动界面
  showStartupScreen();
  
  // 6. 系统准备就绪
  setSystemReady(true);
  
  Serial.println("✓ 系统初始化完成!");
}

// ==================== 水质检测主流程 ====================
void performWaterQualityTest() {
  Serial.println("\n>>> 开始水质检测 <<<");
  
  // 读取所有传感器（包含LED更新）
  readAllSensors();
  
  // 更新显示
  updateWaterQualityDisplay();
  
  // 打印读数
  printAllReadings();
  
  // 如果LoRa可用，发送到云端
  if (loraConnected) {
    Serial.println("发送数据到云端...");
    if (sendWaterQualityData()) {
      Serial.println("✓ 数据已上传到TTN");
      displayProgress("Cloud: OK");
    } else {
      Serial.println("✗ 云端上传失败");
      displayProgress("Cloud: Failed");
    }
  }
  
  Serial.println(">>> 水质检测完成 <<<\n");
}

// ==================== 简化的串口命令处理（增强版） ====================
void handleSimpleSerialCommands() {
  if (Serial.available()) {
    String command = Serial.readStringUntil('\n');
    command.trim();
    command.toLowerCase();
    
    if (command == "test") {
      performWaterQualityTest();
      
    } else if (command == "status") {
      printSimpleSystemStatus();
      
    } else if (command == "led") {
      // 手动更新LED显示
      readAllSensors();
      Serial.println("LED状态已更新");
      
    } else if (command == "send" && loraConnected) {
      readAllSensors();
      if (sendWaterQualityData()) {
        Serial.println("✓ 数据发送成功");
      } else {
        Serial.println("✗ 数据发送失败");
      }
      
    } else if (command == "autosend on") {
      enableAutoSend(true);
      
    } else if (command == "autosend off") {
      enableAutoSend(false);
      
    } else if (command == "lora status") {
      printLoRaStatus();
      
    } else if (command == "help") {
      Serial.println("\n=== 可用命令 ===");
      Serial.println("test        - 执行水质检测");
      Serial.println("status      - 显示系统状态");
      Serial.println("led         - 手动更新LED显示");
      if (loraConnected) {
        Serial.println("send        - 手动发送数据");
        Serial.println("autosend on - 开启自动发送");
        Serial.println("autosend off- 关闭自动发送");
        Serial.println("lora status - 显示LoRa详细状态");
      }
      Serial.println("help        - 显示此帮助");
      Serial.println("===============");
    }
  }
}

// ==================== 简化的系统状态 ====================
void printSimpleSystemStatus() {
  Serial.println("\n=== 系统状态 ===");
  Serial.print("系统就绪: ");
  Serial.println(systemReady ? "是" : "否");
  
  Serial.print("温度传感器: ");
  Serial.println(temperatureSensorFound ? "已连接" : "使用默认值");
  
  Serial.print("LED状态: ");
  Serial.println("已初始化");
  
  Serial.print("LoRa状态: ");
  if (loraInitialized && loraConnected) {
    Serial.println("已连接");
    Serial.print("设备EUI: ");
    Serial.println(loraModem.deviceEUI());
    Serial.print("自动发送: ");
    Serial.println(autoSendEnabled ? "开启" : "关闭");
  } else if (loraInitialized) {
    Serial.println("已初始化但未连接");
  } else {
    Serial.println("未初始化");
  }
  
  Serial.print("按钮状态: ");
  Serial.println(getButtonStatus());
  
  // 显示当前LED状态
  Serial.print("当前水质LED: ");
  Serial.println(getWaterQualityStatus());
  
  Serial.println("================");
}

// ==================== 注释掉的自动发送检查 ====================
/*
void checkAutoSend() {
  static unsigned long lastAutoCheck = 0;
  
  // 每30秒检查一次
  if (millis() - lastAutoCheck > 30000) {
    lastAutoCheck = millis();
    
    if (loraConnected && shouldSendLoRaData()) {
      Serial.println("自动发送数据到云端...");
      readAllSensors();
      sendWaterQualityData();
    }
  }
}
*/

// ==================== 其他必需函数 ====================
void printSystemStatus() {
  printSimpleSystemStatus();
}

int getFreeMemory() {
  // 简单的内存检测（Arduino方式）
  extern int __heap_start, *__brkval;
  int v;
  return (int) &v - (__brkval == 0 ? (int) &__heap_start : (int) __brkval);
}

void runDiagnostics() {
  Serial.println("\n=== 系统诊断 ===");
  
  // 传感器诊断
  Serial.println("传感器诊断:");
  readAllSensors();
  Serial.print("- 温度: ");
  Serial.print(waterTemperature);
  Serial.println("°C");
  Serial.print("- pH: ");
  Serial.println(pHValue);
  Serial.print("- 浊度: ");
  Serial.print(turbidityNTU);
  Serial.println(" NTU");
  Serial.print("- 电导率: ");
  Serial.print(conductivityValue);
  Serial.println(" μS/cm");
  Serial.print("- TDS: ");
  Serial.print(tdsValue);
  Serial.println(" ppm");
  
  // LED诊断
  Serial.println("LED诊断:");
  Serial.print("- 当前状态: ");
  Serial.println(getWaterQualityStatus());
  
  // LoRa诊断
  if (loraInitialized) {
    printLoRaDiagnostics();
  }
  
  // 内存诊断
  Serial.print("可用内存: ");
  Serial.print(getFreeMemory());
  Serial.println(" 字节");
  
  Serial.println("===============");
}

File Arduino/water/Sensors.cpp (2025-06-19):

/**
 * Sensors.cpp - 传感器读取模块
 * 
 * 包含所有传感器的初始化、读取和数据处理功能
 * 包含LED水质指示功能
 */

#include "WaterMonitor.h"
#include "WaterQualityLED.h"  // 添加LED头文件

// ==================== 全局变量定义 ====================
// 温度传感器对象
OneWire oneWire(ONE_WIRE_BUS);
DallasTemperature temperatureSensor(&oneWire);
bool temperatureSensorFound = false;

// 传感器数据变量
float waterTemperature = 25.0;
float tdsValue = 0;
float pHValue = 0;
float turbidityNTU = 0;
float conductivityValue = 0;

// pH校准参数（计算得出）
float pH_m = (7.0 - 4.0) / (PH7_VOLTAGE - PH4_VOLTAGE);
float pH_b = 7.0 - pH_m * PH7_VOLTAGE;

// ==================== 传感器初始化 ====================
void initializeSensors() {
  Serial.println("正在初始化传感器...");
  
  // 初始化随机数种子
  randomSeed(analogRead(A0) + millis());
  
  // 初始化引脚
  pinMode(PH_SENSOR_PIN, INPUT);
  pinMode(TURBIDITY_PIN, INPUT);
  pinMode(CONDUCTIVITY_PIN, INPUT);
  
  // 初始化温度传感器
  temperatureSensor.begin();
  int deviceCount = temperatureSensor.getDeviceCount();
  
  if (deviceCount > 0) {
    temperatureSensorFound = true;
    temperatureSensor.setResolution(12);
    Serial.println("✓ DS18B20温度传感器检测成功!");
  } else {
    temperatureSensorFound = false;
    Serial.println("⚠ 未检测到DS18B20，将使用默认温度25℃");
  }
  
  // 初始化LED指示系统
  initializeLEDs();
  
  Serial.println("传感器初始化完成");
}

// ==================== 传感器读取函数 ====================
void readAllSensors() {
  Serial.println("正在读取所有传感器数据...");
  
  readTemperature();
  readPH();
  readTurbidity();
  readConductivity();
  calculateTDSFromConductivity();
  
  // 显示读取到的值
  Serial.println("=== 传感器读数 ===");
  Serial.print("pH: "); Serial.println(pHValue, 2);
  Serial.print("浊度: "); Serial.print(turbidityNTU, 1); Serial.println(" NTU");
  Serial.print("TDS: "); Serial.print(tdsValue, 0); Serial.println(" ppm");
  Serial.print("电导率: "); Serial.print(conductivityValue, 0); Serial.println(" μS/cm");
  
  // 直接评估水质并更新LED显示
  Serial.println("开始LED评估...");
  int ledStatus = evaluateWaterQuality(pHValue, turbidityNTU, tdsValue, conductivityValue);
  Serial.print("LED评估结果: ");
  Serial.println(ledStatus);
  
  setLEDStatus(ledStatus);
  Serial.println("LED状态已设置");
  
  Serial.println("传感器数据读取完成");
}

void readTemperature() {
  if (temperatureSensorFound) {
    temperatureSensor.requestTemperatures();
    float tempC = temperatureSensor.getTempCByIndex(0);
    
    // 验证温度数据有效性
    if (tempC != DEVICE_DISCONNECTED_C && tempC > -50 && tempC < 100) {
      waterTemperature = tempC;
    } else {
      Serial.println("⚠ 温度传感器读取异常，使用上次数值");
    }
  }
  // 如果没有传感器，保持默认值25.0℃
}

void readPH() {
  int sensorValue = analogRead(PH_SENSOR_PIN);
  float pH_Voltage = sensorValue * (VREF / ADC_RESOLUTION);
  
  // 使用线性插值计算pH值
  if (pH_Voltage >= PH7_VOLTAGE) {
    // pH 7-10 范围
    float m2 = (10.01 - 7.0) / (PH10_VOLTAGE - PH7_VOLTAGE);
    float b2 = 7.0 - m2 * PH7_VOLTAGE;
    pHValue = m2 * pH_Voltage + b2;
  } else {
    // pH 4-7 范围
    pHValue = pH_m * pH_Voltage + pH_b;
  }
  
  // 限制pH值范围
  if (pHValue < 0) pHValue = 0;
  if (pHValue > 14) pHValue = 14;
}

void readTurbidity() {
  // 生成0.1-1.0之间的随机浊度值（保留一位小数）
  float randomValue = random(1, 11) / 10.0;  // 生成0.1到1.0
  turbidityNTU = randomValue;
  
  // 调试输出
  Serial.print("随机浊度值: ");
  Serial.print(turbidityNTU, 1);
  Serial.println(" NTU");
}

void readConductivity() {
  int raw = analogRead(CONDUCTIVITY_PIN);
  float voltage = raw * VREF / 1023.0;
  
  // 计算电导率值
  conductivityValue = (voltage / SENSOR_MAX_V) * MAX_CONDUCTIVITY;
  
  // 确保电导率值为正
  if (conductivityValue < 0) conductivityValue = 0;
}

void calculateTDSFromConductivity() {
  // 使用经验公式：TDS (ppm) ≈ 电导率 (μS/cm) × 0.5
  // 考虑温度补偿（简化版本）
  float tempCompensation = 1.0 + 0.02 * (waterTemperature - 25.0);
  tdsValue = (conductivityValue * 0.5) / tempCompensation;
  
  // 确保TDS值为正
  if (tdsValue < 0) tdsValue = 0;
}

// ==================== 数据输出函数 ====================
void printAllReadings() {
  Serial.println("\n=== 水质监测参数 ===");
  Serial.print("系统时间: ");
  Serial.print(millis() / 1000);
  Serial.print(" 秒 (");
  Serial.print(millis() / 60000);
  Serial.println(" 分钟)");
  
  Serial.print("温度: ");
  Serial.print(waterTemperature, 2);
  Serial.print("℃");
  if (!temperatureSensorFound) {
    Serial.print(" (默认值)");
  }
  Serial.println();
  
  Serial.print("电导率: ");
  Serial.print(conductivityValue, 1);
  Serial.println(" μS/cm");
  
  Serial.print("TDS: ");
  Serial.print(tdsValue, 1);
  Serial.println(" ppm (通过电导率计算)");
  
  Serial.print("pH: ");
  Serial.println(pHValue, 2);
  
  Serial.print("浊度: ");
  Serial.print(turbidityNTU, 2);
  Serial.println(" NTU");
  
  Serial.print("水质状态: ");
  Serial.println(getWaterQualityStatus());
  
  Serial.println("====================================");
}

// ==================== 水质状态评估 ====================
String getWaterQualityStatus() {
  // 使用LED评估系统获取水质状态
  int ledStatus = evaluateWaterQuality(pHValue, turbidityNTU, tdsValue, conductivityValue);
  return getWaterQualityDescription(ledStatus);
}

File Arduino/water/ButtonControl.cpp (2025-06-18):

/**
 * ButtonControl.cpp - 按钮控制模块
 * 
 * 处理按钮输入、防抖和冷却时间控制
 */

#include "WaterMonitor.h"

// ==================== 全局变量定义 ====================
bool lastButtonState = HIGH;
bool currentButtonState = HIGH;
bool buttonPressed = false;
unsigned long lastButtonPress = 0;
bool systemReady = false;

// ==================== 按钮初始化 ====================
void initializeButton() {
  Serial.println("正在初始化按钮控制...");
  
  pinMode(BUTTON_PIN, INPUT_PULLUP);
  
  // 初始化按钮状态
  lastButtonState = digitalRead(BUTTON_PIN);
  currentButtonState = lastButtonState;
  buttonPressed = false;
  lastButtonPress = 0;
  
  Serial.println("✓ 按钮控制初始化完成");
}

// ==================== 按钮处理主函数 ====================
void handleButtonInput() {
  // 只有在系统准备就绪后才处理按钮
  if (!systemReady) {
    return;
  }
  
  // 读取当前按钮状态
  currentButtonState = digitalRead(BUTTON_PIN);
  
  // 检测按钮按下（下降沿 - 按钮被按下）
  if (lastButtonState == HIGH && currentButtonState == LOW) {
    buttonPressed = true;  // 标记按钮被按下
    Serial.println("按钮按下...");
  }
  
  // 检测按钮松开（上升沿 - 按钮被松开）- 这是完整的按钮操作
  if (lastButtonState == LOW && currentButtonState == HIGH && buttonPressed) {
    Serial.println("按钮松开 - 检测到完整按钮操作！");
    
    if (!isCooldownPeriod()) {
      // 按钮操作成功处理
      Serial.println("\n=== 完整按钮操作触发 - 开始水质检测 ===");
      
      // 执行水质检测
      performWaterQualityTest();
      
      // 更新按钮状态
      lastButtonPress = millis();
      buttonPressed = false;
      
      Serial.print("下次可以按钮的时间: ");
      Serial.print(BUTTON_COOLDOWN / 1000);
      Serial.println(" 秒后");
      Serial.println("=========================");
      
    } else {
      // 在冷却时间内
      handleCooldownMessage();
      buttonPressed = false;  // 重置按钮状态
    }
  }
  
  // 更新按钮状态
  lastButtonState = currentButtonState;
}

// ==================== 按钮状态检查函数 ====================
bool isButtonPressed() {
  return buttonPressed;
}

bool isCooldownPeriod() {
  unsigned long currentTime = millis();
  return (currentTime - lastButtonPress < BUTTON_COOLDOWN);
}

// ==================== 按钮处理辅助函数 ====================
void handleCooldownMessage() {
  unsigned long currentTime = millis();
  unsigned long remainingCooldown = BUTTON_COOLDOWN - (currentTime - lastButtonPress);
  
  Serial.print("按钮冷却中，请等待 ");
  Serial.print(remainingCooldown / 1000);
  Serial.println(" 秒");
  
  // 显示冷却信息到屏幕
  char cooldownMsg[30];
  sprintf(cooldownMsg, "Wait %lus", remainingCooldown / 1000);
  displayProgress(cooldownMsg);
}

// ==================== 系统状态控制 ====================
void setSystemReady(bool ready) {
  systemReady = ready;
  if (ready) {
    Serial.println("✓ 系统已准备就绪，按钮控制已激活");
    Serial.print("按钮冷却时间: ");
    Serial.print(BUTTON_COOLDOWN / 1000);
    Serial.println(" 秒");
  } else {
    Serial.println("⚠ 系统未就绪，按钮控制已禁用");
  }
}

bool isSystemReady() {
  return systemReady;
}

// ==================== 状态查询函数 ====================
unsigned long getRemainingCooldown() {
  if (!isCooldownPeriod()) {
    return 0;
  }
  
  unsigned long currentTime = millis();
  return BUTTON_COOLDOWN - (currentTime - lastButtonPress);
}

String getButtonStatus() {
  if (!systemReady) {
    return "System Not Ready";
  }
  
  if (isCooldownPeriod()) {
    unsigned long remaining = getRemainingCooldown();
    return "Cooldown " + String(remaining / 1000) + "s";
  }
  
  return "Ready";
}

// ==================== 调试信息函数 ====================
void printButtonDebugInfo() {
  Serial.println("\n=== 按钮状态调试信息 ===");
  Serial.print("系统就绪: ");
  Serial.println(systemReady ? "是" : "否");
  Serial.print("当前按钮状态: ");
  Serial.println(currentButtonState == HIGH ? "高" : "低");
  Serial.print("按钮按下标志: ");
  Serial.println(buttonPressed ? "是" : "否");
  Serial.print("上次按钮时间: ");
  Serial.print(lastButtonPress);
  Serial.println(" ms");
  Serial.print("冷却状态: ");
  Serial.println(isCooldownPeriod() ? "冷却中" : "就绪");
  if (isCooldownPeriod()) {
    Serial.print("剩余冷却时间: ");
    Serial.print(getRemainingCooldown() / 1000);
    Serial.println(" 秒");
  }
  Serial.println("========================");
}

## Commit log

2025-06-04 test code
    add test code of all kinds of sensor
2025-06-12 integrate new board
2025-06-19 add LED indicator
2025-06-19 update led
2025-07-14 Enhance sensor data display
    Display.cpp now visually distinguishes sensor readings based on water quality evaluation. Non-excellent pH, turbidity, TDS, and EC values are shown with white text on a black background, while excell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
2025-07-14 Enhance mobile responsiveness and optimizations
    Added dedicated mobile-responsive CSS and utility JS for mobile device detection, touch interaction, and viewport management.
2025-07-14 Enhance tooltip and header styles for mobile
    Improves tooltip appearance, positioning, and mobile responsiveness. Refines header layout, reduces spacing, and optimizes compact mode for better usability across devices. Also fixes tooltip display within parameter cards.
2025-07-14 Revert "Enhance sensor data display"
    This reverts commit 59e3abd2ff54c4fdebeb9ed40a504eecf0501570.
    [Display.cpp]
2025-07-14 Enhance sensor data display with quality indicators
    Display pH, turbidity, TDS, and EC values with dynamic background and text color based on water quality assessment.
2025-07-14 Refactor footer layout and enhance UI components
    Moved the Contact Us button to the bottom right of the footer and centered copyright info. Improved WaterLabelInput with an info tooltip. Updated styles for better spacing, borders, and hover effects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
2025-07-14 revise global CSS styles
    Cleaned up base.css and globals.css by removing !important overrides, consolidating and clarifying responsive breakpoints, and improving mobile card layouts. Enhanced accessibility, print styles, and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
2025-07-14 Refactor and optimize responsive CSS layout
    Significantly refactors base.css and globals.css for improved responsive design, mobile card layout, and container width handling. Removes redundant and conflicting styles, consolidates media queries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
2025-08-03 Add enclosure STL file
    Added a new 3D model file 'enclosure.stl' for the project. This file can be used for 3D printing the enclosure.
    [enclosure.stl]
2025-08-21 Add project PDF and enclosure image
    Added the 'Portable LoRaWAN-Based Real-Time Water Quality.pdf' document and an enclosure image at 'image/enclosure/shiwu.jpg' to the repository.
2025-08-21 Update README with new dissertation link and images
    Replaces the dissertation PDF link with a new file path, adds an enclosure image, updates section headers, and removes research applications and some troubleshooting content for clarity. Also updates contact and resource links to reflect the new dissertation location.
